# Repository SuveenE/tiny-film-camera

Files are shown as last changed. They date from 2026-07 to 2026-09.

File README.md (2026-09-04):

# Tiny Film Camera

Tiny Film Camera is an open-source digital camera built around the Raspberry Pi
Zero 2 W and Camera Module 3. It can capture photos and record short video clips
using dedicated photo and video buttons, with three selectable looks (warm, cool,
and black & white) controlled by a physical slider switch. A buzzer provides
feedback for startup and photo capture, and a local photo gallery can be accessed
directly from your phone.

Read about the design and build process in
[Building my own camera](https://suveenellawela.com/thoughts/building-my-own-camera).

<p align="center">
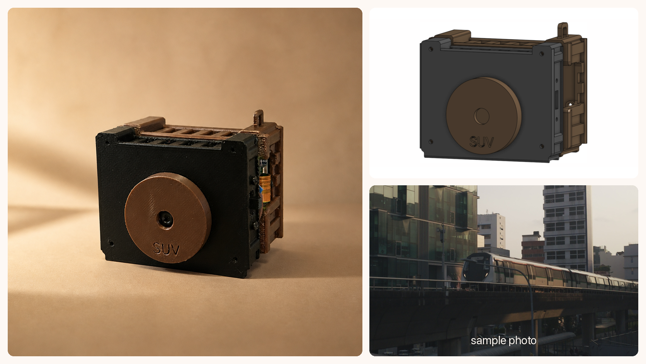
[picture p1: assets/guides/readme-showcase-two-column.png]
Tiny Film Camera assembled, the v1 CAD design, and a sample photo
  
</p>
<p align="center">
  <sub>
    <a href="assets/v1/product-images/camera-launch-warm.png">Assembled camera</a> ·
    <a href="assets/v1/v1-design.png">v1 CAD design</a> ·
    <a href="assets/photo-samples/train-sample-1935x1346.jpg">Sample photo</a> ·
    <a href="assets/photo-samples/train-original-4608x2592.jpg">Original photo (4608 × 2592)</a>
  </sub>
</p>

## What it does

- Use dedicated physical buttons for photos and short video clips.
- Choose Warm, Cool, or Black & white with a three-position hardware switch.
- Capture, browse, download, and delete photos from a phone on the same Wi-Fi.
- Monitor the Waveshare UPS battery from the web interface.
- Apply configurable exposure, white-balance, focus, rotation, and JPEG settings.
- Start the web app and hardware daemons automatically with systemd.

## Hardware

- Raspberry Pi Zero 2 W
- Raspberry Pi Camera Module 3
- Waveshare UPS HAT (C)
- Two momentary buttons (photo and video)
- Optional passive buzzer and SS23D32 three-position switch
- 3D-printed enclosure from [`assets/`](assets/README.md)

See the complete [bill of materials](docs/bom.md) and [setup guide](docs/setup.md).

### Components and wiring

<table>
  <tr>
    <td align="center" width="50%">
      <a href="assets/guides/components.png">
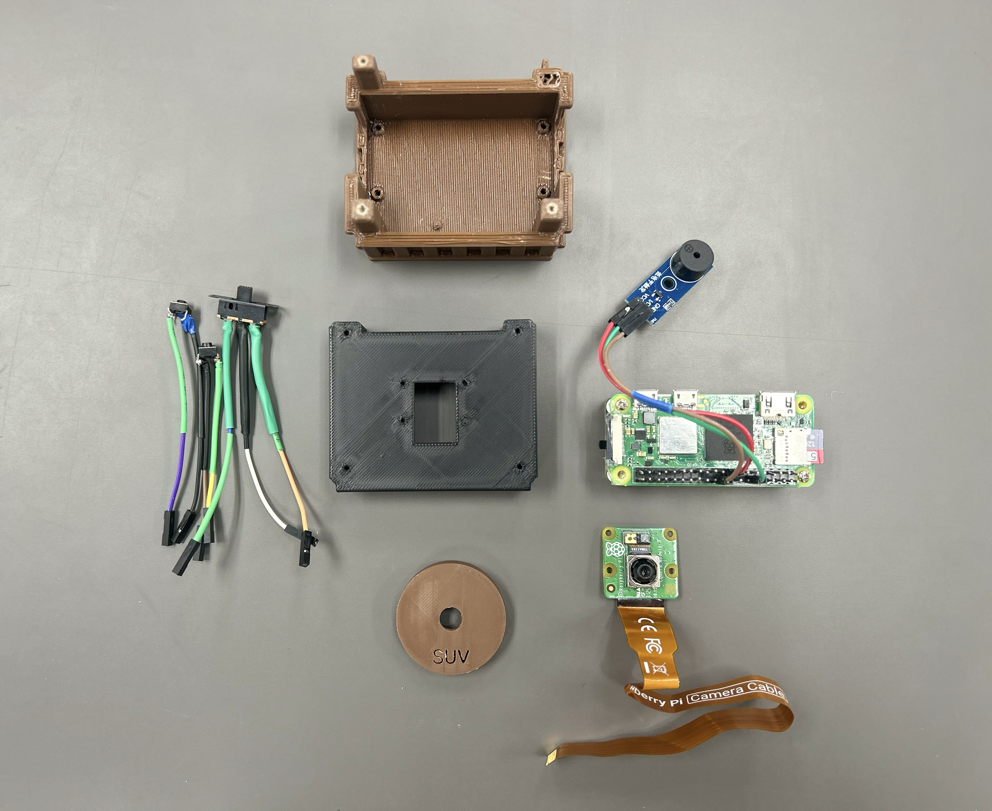
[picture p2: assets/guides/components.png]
Components used to build Tiny Film Camera
        
      </a>
      <br />
      <strong>Components</strong>
    </td>
    <td align="center" width="50%">
      <a href="assets/guides/wiring.png">
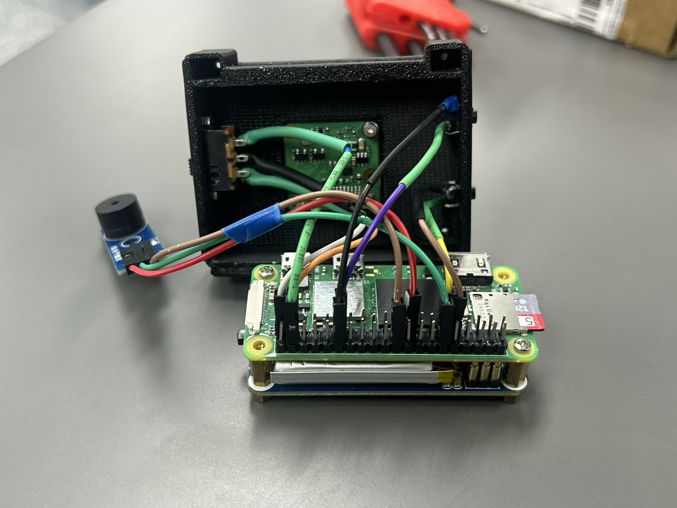
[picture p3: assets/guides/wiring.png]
Tiny Film Camera wiring guide
        
      </a>
      <br />
      <strong>Wiring</strong>
    </td>
  </tr>
</table>

## CAD designs

Browse all [Tiny Film Camera CAD components on Onshape](https://cad.onshape.com/documents?nodeId=a67770dd4e9bb35af20c342a&resourceType=folder).
Download the [printable enclosure files on Printables](https://www.printables.com/model/1827732-raspberry-pi-zero-2-w-camera-module-3-ups-hat-encl/files).

<table>
  <tr>
    <td align="center" width="50%">
      <a href="assets/v1/cad-demo-v1.mp4">
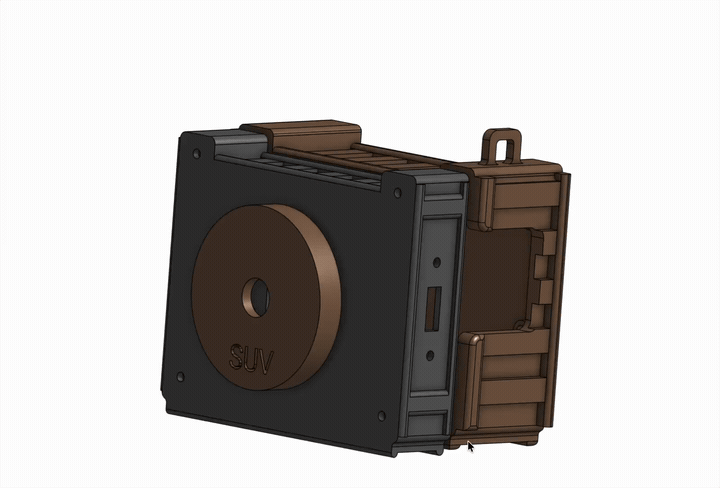
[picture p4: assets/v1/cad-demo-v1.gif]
Animated view of the assembled Tiny Film Camera v1 enclosure
        
      </a>
      <br />
      <strong>Assembled camera</strong>
    </td>
    <td align="center" width="50%">
      <a href="assets/v1/v1-cad.png">
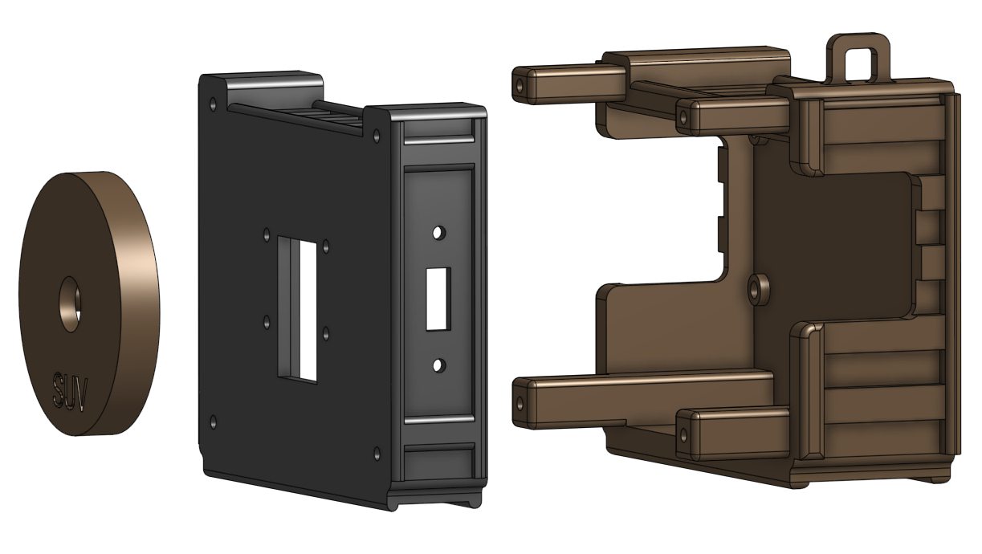
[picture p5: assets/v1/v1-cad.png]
Tiny Film Camera v1 CAD design
        
      </a>
      <br />
      <strong>v1 CAD design</strong>
    </td>
  </tr>
</table>

## Quick start

On a Raspberry Pi running Raspberry Pi OS:

```bash
git clone https://github.com/SuveenE/tiny-film-camera.git
cd tiny-film-camera

sudo apt update
sudo apt install -y \
  ffmpeg python3-picamera2 python3-av python3-pil python3-gpiozero \
  python3-smbus i2c-tools

cp .env.example .env
./scripts/install_service.sh --enable-now
```

Open `http://<pi-ip>:8000` from a phone on the same Wi-Fi network. Captures are
saved under `data/captures/`.

<p align="center">
  <a href="assets/web-app.jpg">
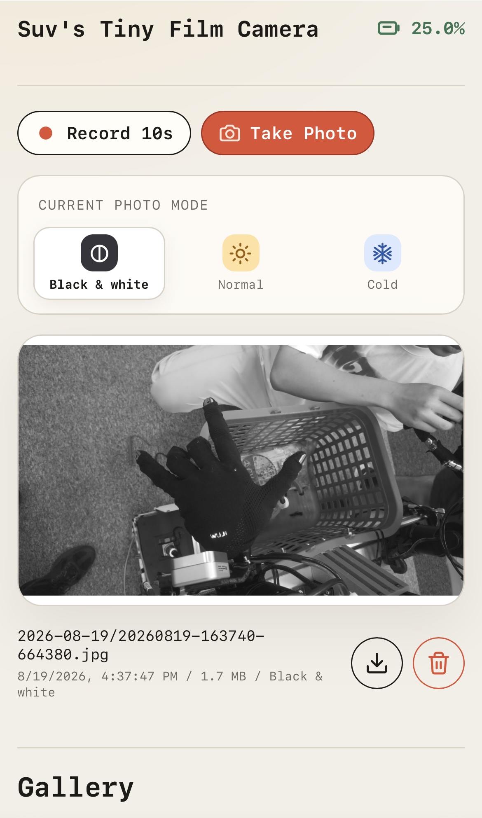
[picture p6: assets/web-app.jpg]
Tiny Film Camera web app showing capture controls, photo modes, battery level, and gallery
    
  </a>
</p>

> [!WARNING]
> The web interface has no authentication. Use it only on a trusted local
> network and do not expose port `8000` to the internet.

## Use it

Take a photo or record a ten-second video from the command line:

```bash
python3 src/tiny-film-cam/capture.py
python3 src/tiny-film-cam/record.py --duration 10
```

Customize the camera, GPIO pins, filters, battery calibration, and service
settings in [`.env.example`](.env.example), then copy the values you need into
your local `.env`.

## Build guides

- [Button, slider, and buzzer wiring](docs/wiring.md)
- [Camera and Raspberry Pi setup](docs/setup.md)
- [Physical shutter](docs/shutter-button.md)
- [Passive buzzer](docs/buzzer.md)
- [Photo-filter switch](docs/filter-switch.md)
- [Commands and service management](docs/commands.md)
- [Troubleshooting](docs/debug.md)
- [Enclosure and printable assets](assets/README.md)

## Limitations

- The Raspberry Pi takes approximately 30 seconds to 1 minute to fully start
  up, so there is a short wait before the camera is ready to use.
- Each photo takes approximately 3 to 6 seconds to process because images are
  captured at full resolution.

## License

Code and original CAD are available under the [MIT License](LICENSE).
Third-party enclosure models retain their upstream Creative Commons licenses;
see [`assets/README.md`](assets/README.md) for attribution.

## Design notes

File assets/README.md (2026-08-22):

# 3D-printable case assets

STL and OpenSCAD files for the tiny-film hardware enclosure.

Original project files under `assets/` (C-bracket spacers and generators) are
covered by the repository [MIT License](../LICENSE). Third-party Printables
models keep their upstream licenses, listed below.

## Photo samples

Full-resolution camera samples, preserved without recompression:

- `photo-samples/train-original-4608x2592.jpg` — original landscape photo,
  4608 × 2592 pixels
- `photo-samples/train-zoomed-1170x2080.jpg` — zoomed-in portrait view,
  1170 × 2080 pixels
- `photo-samples/train-sample-1935x1346.jpg` — landscape sample photo,
  1935 × 1346 pixels

## README collages

- `guides/readme-showcase-with-sample.png` — original showcase with an added
  portrait sample column
- `guides/readme-showcase-two-column.png` — assembled camera on the left, with
  the front-facing CAD card and landscape sample stacked on the right

Regenerate the collages from their checked-in source images:

```bash
python3 assets/guides/generate-readme-showcase.py
python3 assets/guides/generate-readme-showcase-two-column.py
```

## v1 assets

Current enclosure parts, reference renders, and a compressed CAD demo:

- `v1/bottom-cover-v1.stl` — bottom cover
- `v1/camera-cover-v1.stl` — camera cover
- `v1/top-cover-v1.stl` — top cover
- `v1/v1-design.png` — assembled enclosure render
- `v1/v1-cad.png` — CAD workspace render
- `v1/cad-demo-v1.mp4` — short, web-friendly CAD model demo
- `v1/product-images/camera-launch-clean.png` — clean studio product photo
- `v1/product-images/camera-launch-dark.png` — dark studio product photo
- `v1/product-images/camera-launch-warm.png` — warm studio product photo

## Third-party models

### Raspberry Pi Zero 2 Case MK3 Camera

- **Designer:** [XenoTechie](https://www.printables.com/@XenoTechie_72441)
- **Source:** https://www.printables.com/model/799255-raspberry-pi-zero-2-case-mk3-camera
- **License:** [Creative Commons Attribution 4.0 (CC BY)](https://creativecommons.org/licenses/by/4.0/)
- **Files in this repo:**
  - `v0/pi-zero-2w-camera-case-top.stl` — top cover (unmodified)
  - `v0/pi-zero-2w-camera-plate-suv-logo.stl` — camera plate
    remixed with custom “SUV” branding (derivative of the upstream camera
    plate; redistributed under the same CC BY terms with attribution)

### Raspberry Pi Zero 2 WH Waveshare UPS Case

- **Designer:** [PiotrWolinski](https://www.printables.com/@PiotrWolinski_579340)
- **Source:** https://www.printables.com/model/1546215-raspberry-pi-zero-2-wh-waveshare-ups-case
- **License:** [Creative Commons Attribution-ShareAlike 4.0 (CC BY-SA)](https://creativecommons.org/licenses/by-sa/4.0/)
- **Files in this repo:**
  - `v0/pi-zero-2w-waveshare-ups-case-base.stl` — base case (unmodified).
    ShareAlike applies to this file and any adaptations of it.

## Original project files

- `v0/c-bracket-25mm-gap-2.8mm-holes.scad` / `.stl` — 25 mm C-shaped
  spacer with 2.8 mm holes
- `v0/c-bracket-20mm-gap-2.8mm-holes.stl` — 20 mm spacer with 2.8 mm holes
- `v0/c-bracket-20mm-gap-2.1mm-2.8mm-holes.scad` / `.stl` — 20 mm spacer
  with asymmetric 2.1 mm and 2.8 mm holes
- `v0/generate-c-bracket-25mm-gap.py` and
  `v0/generate-c-bracket-20mm-gap.py` — CadQuery STL generators
- `v0/assembled-camera.jpg` — photo of an assembled build

See [`v0/README.md`](v0/README.md) for the version-specific file manifest and
regeneration commands.

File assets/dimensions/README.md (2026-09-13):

# Component dimension references

Mechanical drawings and board-layout references used when designing the
tiny-film enclosure.

- `mini-slide-switch-dimensions.png` — miniature slide-switch dimensions
- `tactile-switch-dimensions.png` — 6×6 mm 4-pin momentary tactile switch
- `pi-camera-rev1.3-dimensions.jpg` — Raspberry Pi Camera board dimensions
- `pi-zero-2w-board-layout.jpg` — Raspberry Pi Zero 2 W board layout
- `pi-zero-dimensions.png` — Raspberry Pi Zero board dimensions

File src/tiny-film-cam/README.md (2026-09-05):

# tiny-film-cam

Raspberry Pi camera application and hardware integration code for Tiny Film.

This folder contains the photo and video capture paths, phone web UI, and the
shutter, battery, buzzer, and filter-switch integrations used by the systemd
services in `deploy/`. It does not include OpenAI image generation or queues.

Run one capture from the project root on the Raspberry Pi:

```bash
python3 src/tiny-film-cam/capture.py
```

Choose one of the three JPEG looks directly with:

```bash
python3 src/tiny-film-cam/capture.py --photo-filter black_and_white
python3 src/tiny-film-cam/capture.py --photo-filter normal
python3 src/tiny-film-cam/capture.py --photo-filter cool
```

If `--output` is omitted, the script writes a timestamped JPEG into
`data/captures/YYYY-MM-DD/`.

To save to a specific filename instead, pass `--output`:

```bash
python3 src/tiny-film-cam/capture.py --output photo1.jpg
```

For a Camera Module 3 full-size still, pass an explicit size:

```bash
python3 src/tiny-film-cam/capture.py --width 4608 --height 2592
```

The default image tuning is set for a film-friendly source capture:

```text
quality=95, sharpness=0.3, contrast=0.85, saturation=0.9,
ev=-0.7, awb_mode=daylight, rotation=180
```

For a more film-friendly source capture, protect highlights and reduce digital
edge bite:

```bash
python3 src/tiny-film-cam/capture.py \
  --width 4608 \
  --height 2592 \
  --sharpness 0.3 \
  --contrast 0.85 \
  --saturation 0.9 \
  --ev -0.7 \
  --awb-mode daylight \
  --rotation 180
```

To capture multiple exposure candidates from one warmed-up camera session:

```bash
python3 src/tiny-film-cam/capture.py \
  --output photo1.jpg \
  --exposure-brackets 0,-0.7,-1.0 \
  --awb-lock
```

Bracketed filenames include the EV value, such as
`photo1_ev+0p0.jpg`, `photo1_ev-0p7.jpg`, and `photo1_ev-1p0.jpg`.

Record a short video (H.264/MP4, 10s by default) into the same
`data/captures/YYYY-MM-DD/` tree:

```bash
python3 src/tiny-film-cam/record.py --duration 10
```

Video recording requires PyAV, ffmpeg, and its `libx264` encoder on the Pi
(`sudo apt install python3-av ffmpeg`) and only supports rotation 0 or 180.
PyAV preserves camera timestamps when frames arrive late. ffmpeg then converts
the recording to constant-frame-rate H.264 that plays reliably in Safari and
places the MP4 index at the front. This final conversion takes additional time
after the requested footage has been recorded, so a 10-second clip takes longer
than 10 seconds to finish. Each new video also gets a small
`<video-name>.poster.jpg` preview for Safari; poster files stay out of the
gallery and are removed with their video.

Run the capture browser:

```bash
python3 src/tiny-film-cam/web.py
```

The web app serves captures from `data/captures/` and exposes:

- `GET /`
- `GET /gallery`
- `GET /api/images` (accepts an optional `limit` query parameter up to 50)
- `POST /api/capture`
- `POST /api/record`
- `DELETE /api/captures/<capture-path>`
- `GET /image/captures/<capture-path>`
- `GET /download/captures/<capture-path>`
- `GET /api/device-details`
- `GET /api/battery`
- `GET /api/filter`
- `GET /latest-image`

For the Wes-inspired cream/cyan filter, real-photo comparisons, and capture or
post-processing commands, see [Wes filter](../../docs/wes-anderson-filter.md).

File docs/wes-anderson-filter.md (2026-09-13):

# Wes-inspired camera filter

`wes_anderson` is a deterministic cream-and-cyan grade inspired by the warm
pastels in Asteroid City. `wes_rose` is a softer pink/blue alternative. These
are original RGB transforms, not official movie LUTs. No AI, synthesis,
random grain, blur, object replacement, or queue is involved.

The grade lifts midtones, gently compresses the tonal endpoints, moves blue
fabric toward cyan and greens toward olive, and separates cream highlights
from warm golden accents. A cached 33 × 33 × 33 Pillow LUT processes the pixels.
The source should be a correctly exposed sRGB photograph, not sensor RAW.

## Capture on the Pi

Run from `/home/suveen/tiny-film`:

```bash
python3 src/tiny-film-cam/capture.py \
  --photo-filter wes_anderson \
  --sharpness 0.3 --rotation 0 \
  --keep-original
```

This writes a timestamped JPEG and filter-version sidecar under `data/captures`.
`--keep-original` also saves the same rotated, ungraded frame as
`<name>.original.png`, with a Normal sidecar. This is lossless ISP output,
not Bayer RAW. Omit the option for faster saving and less storage use.

The command uses the sensor's full 4608 × 2592 resolution. Add
`--width 2304 --height 1296` for quicker experiments. Rotation 0 is correct for
the camera's position during this experiment; the project's normal rotation
remains 180. Exposure 0 worked for this room; it is not a universal exposure.
Start there and lower exposure if important highlights clip.

The selected filter supplies contrast, saturation, EV, and warmup from its
capture profile in `photo_filters.py`. Cool and both Wes aliases use contrast
1, saturation 1, EV 0, and a 4-second warmup. Warmup lets focus, exposure, and
auto white balance settle; white balance is then locked for that capture. This
does not lock gains across separate invocations or changing lighting. CLI
options can temporarily override a profile for a controlled experiment.

## Grade an existing photograph

Run from the project root on either the Pi or a computer with Pillow:

```bash
python3 src/tiny-film-cam/grade.py original.png wes.jpg
python3 src/tiny-film-cam/grade.py original.png softer.png --strength 0.7
python3 src/tiny-film-cam/grade.py original.png rose.jpg --photo-filter wes_rose
```

Always choose a new output filename. The tool refuses to overwrite the input,
existing output, or its metadata. It honors EXIF orientation, converts tagged
ICC inputs to sRGB, and saves a JSON sidecar with source, strength, and filter
version. JPEG quality is 95 with 4:4:4 sampling; PNG preserves exact graded
pixels. Input EXIF is not copied into the output. An untagged input is assumed
to be sRGB. Profile conversion requires Pillow's ImageCms support.

Camera capture and this tool use `apply_photo_filter` from `photo_filters.py`.
Given identical RGB inputs, filter name, and strength 1, their graded pixels
are identical. JPEG files can differ if encoder settings differ.

## Physical switch

The existing **Cool** toggle now applies the same cream-and-cyan LUT as
`wes_anderson`. Keep `TINY_FILM_FILTER_RIGHT=cool` in `.env`; the selection ID
and mode badge remain `cool`. New Cool photos record **Cool · Wes pastels**,
version 4, so their metadata distinguishes this grade from earlier Cool photos.
`--photo-filter cool` and `--photo-filter wes_anderson` produce identical pixels.

After deploying, restart the shutter and web services to load the new filter.
No switch environment changes are needed. The same LUT also works when `cool`
is selected through `TINY_FILM_CAPTURE_FILTER`. The four profile controls are
no longer read from `.env`; exposure and white balance still depend on scene
lighting.

## Experiment: 5 September 2026

Real IMX708 Camera Module 3 images are in `data/captures/wes-lab-20260905/`
on the Pi and local workspace; they are intentionally ignored by Git.

- Baseline: existing camera defaults, 2304 × 1296; upside down for this placement.
- Exposure sweep: neutral ISP settings, rotation 0, 4-second warmup, EV 0,
  +0.7, +1.0; fixed color gains and lens position across the sweep.
  EV +0.7 put about 7% of channel samples at 254 or above. EV 0 retained
  highlight detail, so the LUT supplies the brightness lift instead.
- First iteration: subtle desert and rose grades. The user chose cream/cyan,
  then correctly noted the subtle result did not look strongly Wes-inspired.
- Second iteration: stronger cream/cyan separation and midtone lift; the main
  `wes_anderson` v1 filter uses this direction.
- Full resolution: `full-wes.jpg` plus its `.original.png`; later grading and
  saving with the same JPEG settings produced a byte-identical JPEG.
- A same-room comparison after dark used identical Cool settings except for
  warmup. At 0.5 seconds, mean RGB was 171/148/108 and the image was visibly
  yellow; at 4 seconds it was 156/148/124 with cleaner cream and cyan
  separation. Cool therefore keeps the 4-second warmup in its filter profile.
- Three repeated full-resolution LUT runs produced identical pixel SHA-256
  hashes. After removing an unnecessary RGB copy, measured processing was
  6.06 seconds first run, then 2.86 and 2.45 seconds. JPEG encoding took 0.93
  seconds. Times vary with Pi load, swap, and LUT cache state; these exclude
  loading, capture warmup, and optional PNG saving.
- Full-resolution mean luma rose from 119.4 to 150.6 (0–255). The graded JPEG
  contained no pixels with any channel at 255 in this scene. This is not a
  guarantee against clipping for every input, particularly saturated colors.

One repeated capture exposed a camera shutdown stall after the files had been
saved. The capture path was changed to stop streaming immediately after the
array is captured, before PNG saving and grading. A reboot released the stuck thread. After the change, three consecutive
full-resolution captures completed: 40.63 seconds with a lossless original,
then 12.02 and 11.97 seconds for JPEG-only output, all including 4-second
warmup. This is a small repeat test, not a long-run soak test.

Useful artifacts: `final-comparison.jpg`, `iteration-two.jpg`,
`benchmark.json`, `image-metrics.json`, and exposure metadata JSON files.

## What remains to tune

This is a working color look, not a claim that an arbitrary room becomes a
Wes Anderson film still. The available scene is mostly neutral and the camera
is off-center. For a better visual test, place the camera level and directly
opposite the bed, center the headboard, remove the foreground obstruction,
and include a mustard/cream object with one cyan or red accent. Use broad,
soft light. Then compare Normal and Wes from the same frame again.

Only this indoor scene has been visually tuned. Before treating it as a
universal preset, check daylight, skin tones, foliage, saturated reds, and
low light. Evaluate white balance and exposure separately from the look;
a static LUT cannot repair mixed lighting or recover clipped sensor detail.

Reference: [Wes Anderson Color Palette Explained](https://spotlightfx.com/blog/wes-anderson-color-palette).

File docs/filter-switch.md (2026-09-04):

# Set up the photo-filter switch

The SS23D32 switch selects **Black & white**, **Normal**, or **Cool** for new
photos. Videos are unchanged.

The filter service is the only process that reads the switch GPIO pins. It
debounces the contacts and writes the current selection to
`data/filter-state.json`; web and physical-button captures read that state
immediately before taking each photo. If the state is missing, invalid, or
stale, captures fall back to **Normal** and the web badge reports the fallback.
Each saved photo also records the filter it used, so its gallery label does not
change when the switch moves later.

## 1. Identify the terminals

Power off and unplug the Pi. Choose either row of three switch terminals:

```text
outer A    common    outer B
unused     unused    unused
```

With a multimeter in continuity mode, confirm that `common` connects to one
outer terminal at each end position and neither outer terminal in the centre.

## 2. Wire one row

| Switch terminal | Raspberry Pi Zero 2 W |
| --- | --- |
| outer A | BCM GPIO 26, physical pin 37 |
| common | GND, physical pin 39 |
| outer B | BCM GPIO 20, physical pin 38 |

Leave the second row disconnected. **No resistor is required** because the code
enables the Pi's internal pull-ups. Do not connect the switch to 3.3 V or 5 V.
GPIO 26 and GPIO 20 avoid the photo button (GPIO 5), video button (GPIO 17),
buzzer (GPIO 18), and UPS I2C pins (GPIO 2 and GPIO 3).

## 3. Test the switch

Boot the Pi, open the project directory, and install `gpiozero` if needed:

```bash
sudo apt install -y python3-gpiozero
sudo systemctl stop tiny-film-filter.service 2>/dev/null || true
python3 src/tiny-film-cam/filter_switch_test.py
```

Move the switch through all three positions. The expected readings are:

| GPIO 26 | GPIO 20 | Filter |
| --- | --- | --- |
| LOW | HIGH | Black & white |
| HIGH | HIGH | Normal |
| HIGH | LOW | Cool |

Press `Ctrl+C` when finished. `LOW / LOW` indicates incorrect wiring.

If Black & white and Cool are physically reversed, add this to `.env` rather
than resoldering:

```dotenv
TINY_FILM_FILTER_LEFT=cool
TINY_FILM_FILTER_RIGHT=black_and_white
```

## 4. Install and verify the service

```bash
./scripts/install_service.sh --enable-now
sudo systemctl status tiny-film-filter.service --no-pager
curl -s http://localhost:8000/api/filter | python3 -m json.tool
```

The API should report the current `position`, `selection`, and `active_filter`.
Move the switch and rerun the `curl` command to verify each position.

## 5. Test a photo

Open `http://<pi-ip>:8000`. Confirm that the **Photo filter** badge follows the
switch, then take one photo in each position. The gallery should show the filter
used for every photo.

For service logs:

```bash
sudo journalctl -u tiny-film-filter.service -f
```

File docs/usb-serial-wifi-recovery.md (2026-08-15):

# Recover Wi-Fi over USB Serial

Use this procedure when a Raspberry Pi Zero 2 W will not join Wi-Fi and no
mini-HDMI display is available. It provides a temporary login console through
the Pi's micro-USB data port; the SD card does not need to be reflashed.

## Root cause found

The hotspot credentials stored on the boot partition were correct, the Wi-Fi
radio was enabled, and the Pi could see the 2.4 GHz hotspot. However,
`nmcli connection show` contained no saved Wi-Fi profile, so NetworkManager had
nothing to connect to automatically.

## Enable the temporary serial console

Shut down the Pi, put its SD card in another computer, and back up `config.txt`
and `cmdline.txt` from the `bootfs` partition.

Add this under `[all]` in `config.txt`:

```ini
dtoverlay=dwc2,dr_mode=peripheral
```

Add these space-separated parameters to the existing single line in
`cmdline.txt`:

```text
modules-load=dwc2,g_serial console=ttyGS0,115200 systemd.wants=serial-getty@ttyGS0.service
```

Keep all existing `cmdline.txt` content on that same line. Safely eject the SD
card and return it to the Pi.

Connect a known data-capable micro-USB cable between the computer and the Pi's
port labelled **USB**, not **PWR IN**. This cable supplies both data and power;
do not attach a second power source at the same time.

On macOS, locate and open the serial device:

```bash
ls /dev/cu.usbmodem*
screen /dev/cu.usbmodem11301 115200
```

Replace `usbmodem11301` with the name reported on the host. On Linux, the
device is usually `/dev/ttyACM0`. Press Enter if the login prompt is not
immediately visible, then log in with the Pi user account.

## Diagnose and connect

Check the radio, interface, saved profiles, and visible networks:

```bash
nmcli radio
nmcli device status
rfkill list
nmcli connection show
sudo nmcli device wifi rescan ifname wlan0
nmcli -f IN-USE,SSID,CHAN,FREQ,SIGNAL,SECURITY device wifi list ifname wlan0
```

If the hotspot is visible but has no saved profile, create one without putting
the password in shell history:

```bash
sudo nmcli --ask device wifi connect "<SSID>" ifname wlan0
```

Enter the hotspot password when prompted. Confirm the connection, IP address,
route, and automatic reconnection:

```bash
nmcli device status
ip -4 -br address show wlan0
ip route
nmcli -g connection.autoconnect connection show "<SSID>"
ping -c 3 1.1.1.1
```

## Remove the temporary console

After Wi-Fi and SSH work, remove the added `dtoverlay` line from `config.txt`
and the three added parameters from `cmdline.txt`:

```text
modules-load=dwc2,g_serial
console=ttyGS0,115200
systemd.wants=serial-getty@ttyGS0.service
```

Reboot the Pi. Removing the temporary console avoids leaving a physical USB
login interface enabled.

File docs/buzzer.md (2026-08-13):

# Feedback Buzzer

Add an optional passive buzzer so the physical shutter gives audible cues.
The shutter daemon (`src/tiny-film-cam/shutter_daemon.py`) drives these sounds:

| Sound | When |
|---|---|
| **minimal** | Startup settled and Picamera2 detected the camera (default ready cue) |
| **click** | Frame captured (default; shorter/softer tick than minimal) |
| **gentle** | Frame-captured option with a descending two-note cue |
| **shutter** | Frame-captured option with two dry mechanical-style taps |
| **sparkle** | Frame-captured option with a bright three-note arpeggio |
| **chirp** | Video recording started |
| **double** | Video saved |
| **alert** | Capture or recording failed |

By default the shutter daemon uses a **passive** buzzer on **BCM GPIO 18**.
Leave `TINY_FILM_BUZZER_PIN` blank in `.env`, or pass `--no-buzzer`, to disable.

## Hardware

This project uses a **passive** buzzer module (PWM-driven, not an active beeper
with a built-in oscillator). The BOM lists the module with pins **VCC**, **I/O**,
and **GND**.

## Wiring

Avoid BCM GPIO 5 (photo button), BCM GPIO 17 (video button), and BCM GPIO 2/3
(UPS HAT I2C). Use **BCM GPIO 18** (physical pin 12):

```
Buzzer VCC ──→ 3V3          (physical pin 1 or 17)
Buzzer GND ──→ GND          (physical pin 6 or 14)
Buzzer I/O ──→ BCM GPIO 18  (physical pin 12)
```

Power the module from **3.3V**, not 5V — the Pi GPIO is 3.3V and matches the
module's 3.3–5.5V supply range.

## Test the sounds

With the module wired, run the demo from the project root on the Pi:

```bash
python3 src/tiny-film-cam/buzzer.py
```

Or audition the four photo sounds individually:

```bash
python3 src/tiny-film-cam/buzzer.py --sound gentle --volume 1.0
python3 src/tiny-film-cam/buzzer.py --sound shutter --volume 1.0
python3 src/tiny-film-cam/buzzer.py --sound sparkle --volume 1.0
python3 src/tiny-film-cam/buzzer.py --sound minimal --volume 1.0
```

The old `--sound beep` name remains as an alias for `gentle`.

If those four still appear to have the same pitch, run the diagnostic at full
volume:

```bash
python3 src/tiny-film-cam/buzzer.py --sound pitch-test --volume 1.0
```

It plays a long 1.5 kHz tone followed by a long 2.5 kHz tone. A passive buzzer
will produce two unmistakably different pitches. If both pitches sound the
same, the connected module is an **active buzzer** with its own fixed-frequency
oscillator; software can vary only its pulse rhythm, not its pitch.

Default pin is BCM 18. Override with `--pin` if needed. Use `--active` only if
you wired a simple on/off active buzzer instead.

Passive modules with a drive transistor ignore PWM duty cycle (they stay full
loud while the pin is high). Loudness is controlled by bursting the tone
on/off — lower `--volume` means shorter bursts. Compare:

```bash
python3 src/tiny-film-cam/buzzer.py --sound gentle --volume 0.10
python3 src/tiny-film-cam/buzzer.py --sound gentle --volume 0.3
```

## Using it with the shutter

No `.env` entries are required for the default wiring (GPIO 18, passive).
With the defaults, the daemon waits for systemd to finish booting, allows five
more seconds for startup disk activity to settle, waits until Picamera2 detects
the camera, and then plays `minimal` once
at volume `0.90`. When the daemon is run outside systemd, only the five-second
settle delay applies. A softer `click` at volume `0.30` plays immediately after
the camera returns a frame, before rotation, JPEG encoding, and disk saving.
If an existing `.env` overrides older buzzer defaults, set:

```bash
TINY_FILM_BUZZER_READY_DELAY_SECONDS=5
TINY_FILM_BUZZER_PHOTO_SOUND=click
TINY_FILM_BUZZER_VOLUME=0.90
TINY_FILM_BUZZER_PHOTO_VOLUME=0.30
```

Restart the shutter service after deploying code that includes the buzzer:

```bash
sudo systemctl restart tiny-film-shutter.service
```

Or run the daemon directly:

```bash
python3 src/tiny-film-cam/shutter_daemon.py
```

To disable sound, leave the pin blank in `.env` or pass `--no-buzzer`:

```bash
TINY_FILM_BUZZER_PIN=
```

```bash
python3 src/tiny-film-cam/shutter_daemon.py --no-buzzer
```

## Configuration

| Setting | Env var | CLI flag | Default |
|---|---|---|---|
| Buzzer pin | `TINY_FILM_BUZZER_PIN` | `--buzzer-pin` / `--no-buzzer` | `18` (blank = disabled) |
| Buzzer type | `TINY_FILM_BUZZER_ACTIVE` | `--buzzer-active` / `--buzzer-passive` | passive |
| Ready settle delay | `TINY_FILM_BUZZER_READY_DELAY_SECONDS` | `--buzzer-ready-delay` | `5` seconds after boot finishes |
| Photo sound | `TINY_FILM_BUZZER_PHOTO_SOUND` | `--buzzer-photo-sound` | `click` |
| Ready/video volume | `TINY_FILM_BUZZER_VOLUME` | `--buzzer-volume` | `0.90` |
| Photo volume | `TINY_FILM_BUZZER_PHOTO_VOLUME` | `--buzzer-photo-volume` | `0.30` |

## Notes

- The buzzer is best-effort: if `gpiozero` is missing or the pin can't be
  claimed, the daemon logs a warning and keeps capturing silently.
- Only the physical shutter path beeps. Web UI captures already show on-screen
  confirmation and run in a separate process.
- Tones play on a background thread, so they never delay the next capture.
- Stay near **1.5–2.5 kHz** for this module; that is its claimed tone range.
- A passive piezo can only make simple square-wave tones, not play sampled
  camera audio. The presets use short timing and musical intervals to make the
  most of that hardware.
- Burst volume gating retains at least three complete carrier cycles per pulse
  so low-volume playback does not mask the selected pitch.
- Volume is burst density rather than electrical amplitude: `1.0` drives the
  carrier continuously, while `0.35` drives it for roughly 35% of the playback
  time. Perceived loudness is not linear and varies by buzzer module.

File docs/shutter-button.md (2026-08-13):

# Photo and Video Buttons

Wire two 4-pin momentary tactile switches to give photo and video capture their
own physical buttons. The shutter daemon (`src/tiny-film-cam/shutter_daemon.py`)
listens for both and captures using the same settings as the web UI.

Press the **photo button** for a still image. Press the **video button** to
record one video clip (10 seconds by default).

## Wiring

A 4-pin tactile switch has two pairs of internally connected legs. For each
button, use one leg from each side of the switch—not two legs from the same
connected pair. Confirm the sides with a continuity tester if the switch body
does not make them clear.

```
Photo button, one side ──→ BCM GPIO 5 (physical pin 29)
Photo button, other side ─→ GND       (physical pin 30, or any GND)

Video button, one side ──→ BCM GPIO 17 (physical pin 11)
Video button, other side ─→ GND        (physical pin 9, or any GND)
```

The two buttons can share a GND connection. On each 4-pin switch, the unused
two legs can be left unconnected; they duplicate the connected legs for
mechanical stability.

The daemon enables the Pi's internal pull-up resistor on both GPIOs by default,
so each reads HIGH at rest and goes LOW when its button is pressed. No external
resistors are required. Power the Pi off before changing the wiring, and do not
connect either button to 5 V.

## Running

```bash
python3 src/tiny-film-cam/shutter_daemon.py
```

Or enable the systemd service for auto-start on boot:

```bash
./scripts/install_service.sh --enable-now
```

The service file is at `deploy/tiny-film-shutter.service`.

## Configuration

| Setting | Env var | CLI flag | Default |
|---|---|---|---|
| Photo GPIO pin | `TINY_FILM_PHOTO_BUTTON_PIN` | `--photo-pin` | 5 |
| Video GPIO pin | `TINY_FILM_VIDEO_BUTTON_PIN` | `--video-pin` | 17 |
| Pull direction (both) | `TINY_FILM_BUTTON_PULL_UP` | `--pull-up` / `--pull-down` | pull-up |
| Debounce time | `TINY_FILM_BUTTON_BOUNCE_SECONDS` | `--bounce-time` | 0.15 s |
| Video length | — | `--video-duration` | 10 s |

`TINY_FILM_BUTTON_PIN` and `--pin` remain supported as legacy names for the
photo pin. The new photo-specific setting takes precedence.

When upgrading an existing installation that still has
`TINY_FILM_BUTTON_PIN=17`, replace it with the explicit current mapping:

```dotenv
TINY_FILM_PHOTO_BUTTON_PIN=5
TINY_FILM_VIDEO_BUTTON_PIN=17
```

All capture settings (quality, EV, rotation, AWB, etc.) are inherited from env
vars or can be passed as CLI flags — run with `--help` for the full list.

For optional audible feedback from a passive buzzer module, see
[buzzer.md](buzzer.md).

## Notes

- Button presses are queued and handled in order. A press received while a
  photo or video is in progress runs as soon as the camera is free, without
  overlapping camera access.
- Holding a button does not change its action or repeatedly trigger it: the
  photo button takes one photo and the video button records one fixed-length
  clip per press.
- Photos and videos land in the same output directory as the web UI captures, so
  they appear in the gallery immediately.
- If using pull-down wiring instead, connect the switch between GPIO and 3V3
  and pass `--pull-down`.

## Readiness and repeated-photo test

The startup ready cue now plays only after system startup has settled and
Picamera2 detects a camera. Wait for that cue before taking the first photo. The
same moment appears in the service log as `Tiny Film is ready for photos`.

First test repeated camera capture without involving the physical switch. Stop
the two camera-using services, load the deployed settings, and run five
simulated presses exactly five seconds apart:

```bash
sudo systemctl stop tiny-film-shutter.service tiny-film-web.service
set -a
source .env
set +a
python3 src/tiny-film-cam/shutter_diagnostic.py --count 5 --interval 5
sudo systemctl start tiny-film-web.service tiny-film-shutter.service
```

A successful run ends with `Diagnostic PASSED: 5/5 requests completed`. It also
prints the time from each request to its sensor frame and saved JPEG. A failed
run exits non-zero and prints the exception for the failed request.

Then test the physical button while following the service log:

```bash
sudo journalctl -u tiny-film-shutter.service -f -o cat
```

After the ready cue, press the photo button five times with at least five
seconds between presses. Each press must produce one uninterrupted sequence of
messages with the same request number:

```text
Photo request #1 queued
Photo request #1 started ... after button press
Saved 1 photo(s): ...
Photo request #1 finished in ...
```

If a press has no `queued` message, investigate the button wiring or GPIO
input. If it queues and then logs `Capture failed`, investigate the camera or
capture pipeline. A large `started ... after button press` value means an
earlier photo or video was still using the camera; the request remains queued
instead of being discarded.

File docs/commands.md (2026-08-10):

# Commands

## Take a photo
```bash
rpicam-still -o photo1.jpg --quality 95 --sharpness 0.5 --contrast 0.9 --saturation 0.9
```

## Take a film-friendlier highlight-protected photo
```bash
python3 src/tiny-film-cam/capture.py \
  --output photo1.jpg \
  --quality 95 \
  --sharpness 0.3 \
  --contrast 0.85 \
  --saturation 0.9 \
  --ev -0.7 \
  --awb-mode daylight \
  --rotation 180
```

## Take an exposure bracket
```bash
python3 src/tiny-film-cam/capture.py \
  --output photo1.jpg \
  --exposure-brackets 0,-0.7,-1.0 \
  --awb-lock
```

## Take a photo with the Python capture code
```bash
python3 src/tiny-film-cam/capture.py
```

## Take a full-size Camera Module 3 photo
```bash
python3 src/tiny-film-cam/capture.py --width 4608 --height 2592
```

## Record a short video (10s default)
```bash
python3 src/tiny-film-cam/record.py
```

## Record a custom-length video
```bash
python3 src/tiny-film-cam/record.py --duration 5 --width 1920 --height 1080 --fps 15
```

## Transfer photos to local machine
```bash
scp -r <pi-user>@<pi-ip>:/home/<pi-user>/tiny-film/data/captures .
```

Example (Pi over phone hotspot):
```bash
scp -r suveen@172.20.10.2:/home/suveen/tiny-film/data/captures .
```

## Test the feedback buzzer
```bash
python3 src/tiny-film-cam/buzzer.py
```

## Play one buzzer sound
```bash
python3 src/tiny-film-cam/buzzer.py --sound sparkle --volume 1.0
python3 src/tiny-film-cam/buzzer.py --sound minimal --volume 1.0
```

## Check whether the buzzer can change pitch
```bash
python3 src/tiny-film-cam/buzzer.py --sound pitch-test --volume 1.0
```

## Install boot services
```bash
./scripts/install_service.sh --enable-now
```

## Restart services
```bash
./scripts/restart_services.sh
```

## Service status
```bash
sudo systemctl status tiny-film-web.service tiny-film-shutter.service tiny-film-battery.service --no-pager
```

## Take a photo through the web server
```bash
curl -X POST http://localhost:8000/api/capture
```

## Record a video through the web server
```bash
curl -X POST http://localhost:8000/api/record
```

## Read battery details through the web server
```bash
curl http://localhost:8000/api/battery
```

## Follow service logs
```bash
sudo journalctl -u tiny-film-web.service -u tiny-film-shutter.service -u tiny-film-battery.service -f
```

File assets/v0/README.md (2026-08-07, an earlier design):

# Tiny Film v0 hardware files

Files use lowercase, descriptive names so printable outputs and editable sources
are easy to identify. Dimensions are in millimetres.

## Case parts

| File | Purpose |
| --- | --- |
| `pi-zero-2w-waveshare-ups-case-base.stl` | Base for the Pi Zero 2 W and Waveshare UPS HAT |
| `pi-zero-2w-camera-case-top.stl` | Camera case top cover |
| `pi-zero-2w-camera-plate-suv-logo.stl` | Camera plate remixed with the SUV logo |

These models retain their upstream Creative Commons licences and attribution;
see the parent [`assets/README.md`](../README.md).

## Additional case part

| File | Purpose |
| --- | --- |
| `pi-camera-top-cover-v0.stl` | Updated v0 Raspberry Pi camera top cover |

## C-bracket spacers

| Printable STL | Editable source | Generator |
| --- | --- | --- |
| `c-bracket-25mm-gap-2.8mm-holes.stl` | `c-bracket-25mm-gap-2.8mm-holes.scad` | `generate-c-bracket-25mm-gap.py` |
| `c-bracket-20mm-gap-2.8mm-holes.stl` | — | — |
| `c-bracket-20mm-gap-2.1mm-2.8mm-holes.stl` | `c-bracket-20mm-gap-2.1mm-2.8mm-holes.scad` | `generate-c-bracket-20mm-gap.py` |

Run the CadQuery generators from the repository root:

```bash
python3 assets/v0/generate-c-bracket-25mm-gap.py
python3 assets/v0/generate-c-bracket-20mm-gap.py
```

The generators overwrite their corresponding STL output. The bracket sources
and generators are covered by the repository MIT licence.

## Reference photo

`assembled-camera.jpg` shows the completed v0 build.

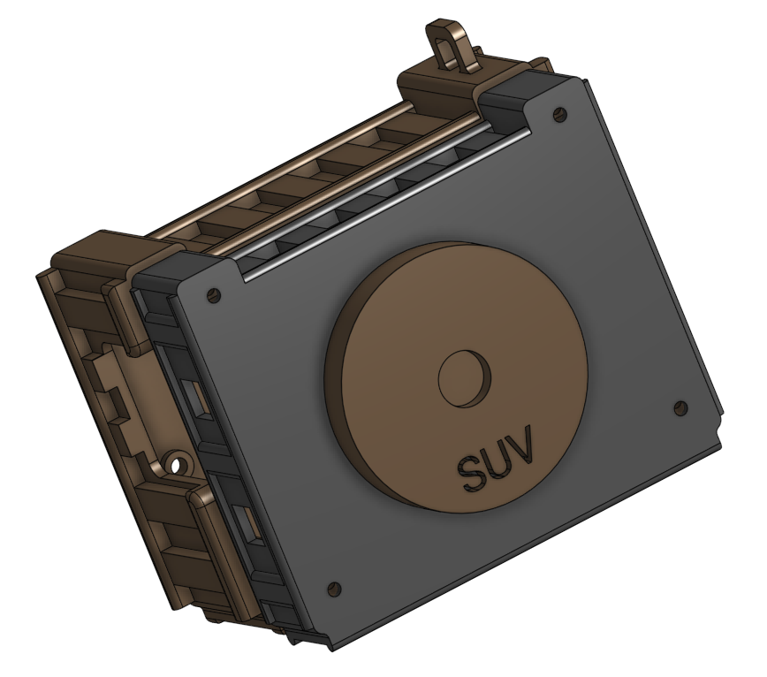
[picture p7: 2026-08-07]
assets/v1/v1-design.png

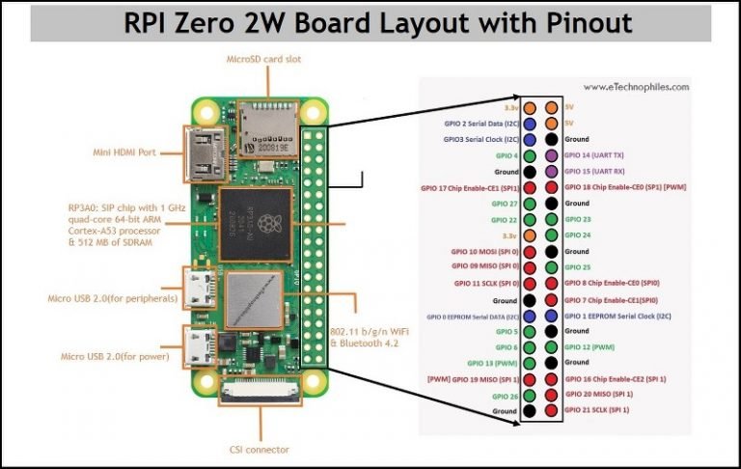
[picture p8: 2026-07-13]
assets/dimensions/pi-zero-2w-board-layout.jpg

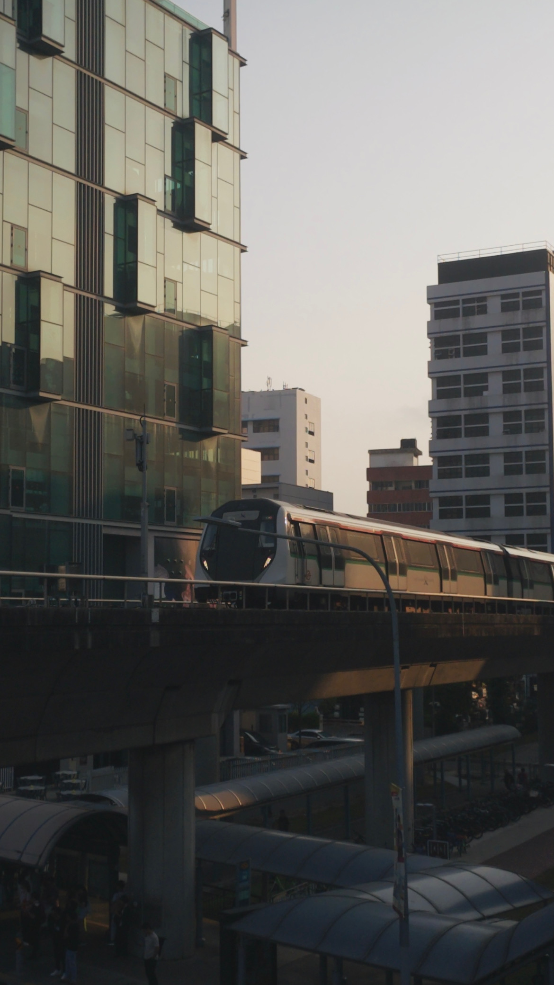
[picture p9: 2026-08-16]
assets/photo-samples/train-zoomed-1170x2080.jpg

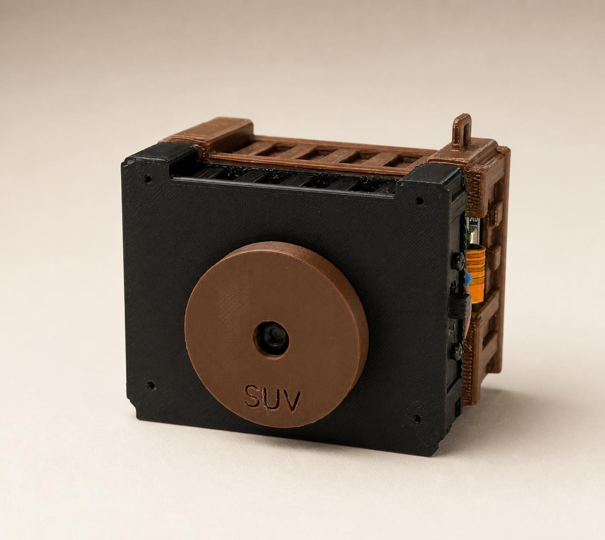
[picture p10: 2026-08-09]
assets/v1/product-images/camera-launch-clean.png

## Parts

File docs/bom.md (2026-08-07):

# Bill of Materials

- Raspberry Pi Zero 2W
- Raspberry Pi Camera Module 3
- Raspberry Pi Camera Cable (Standard to Mini, 200mm)
- MicroSD Card (A1, 32GB)
- Uninterruptible Power Supply UPS HAT For Raspberry Pi Zero, Stable 5V Power Output
- 2 × momentary tactile push buttons (one photo, one video)
- [Passive Buzzer Module (DC 3.3V/5V)](http://shopee.sg/Passive-Buzzer-Module-DC-3.3V-5V-i.199330107.27956752948)
- [3-Position 2P2T DPDT Panel Mount Slide Switch (SS23D32)](https://shopee.sg/10-x-DC-0.5A-50V-3-Position-2P2T-DPDT-Panel-Mount-Slide-Switch-SS23D32-i.1413766173.51250063839)

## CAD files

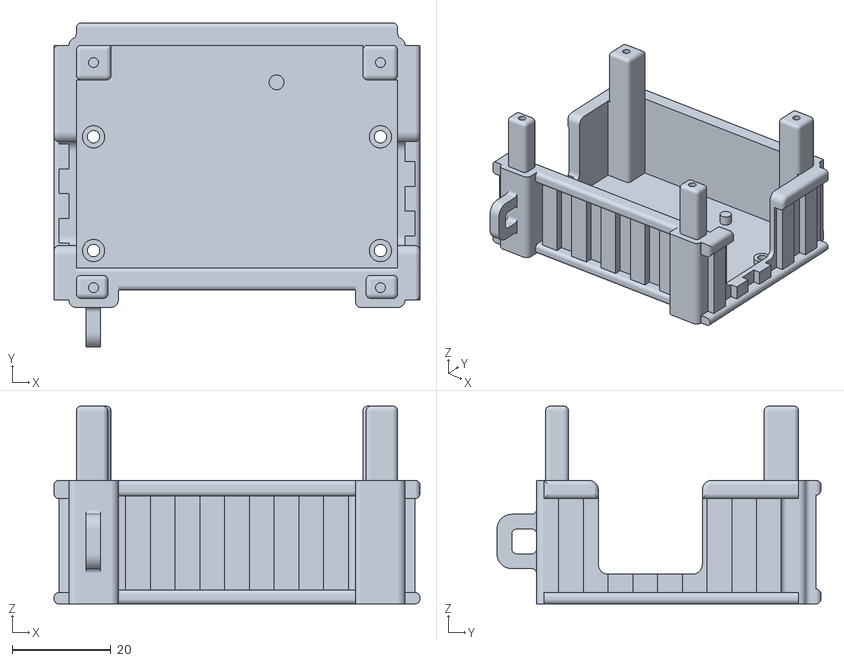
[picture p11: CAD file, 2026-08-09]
assets/v1/bottom-cover-v1.stl
74.0 x 65.5 x 40.0

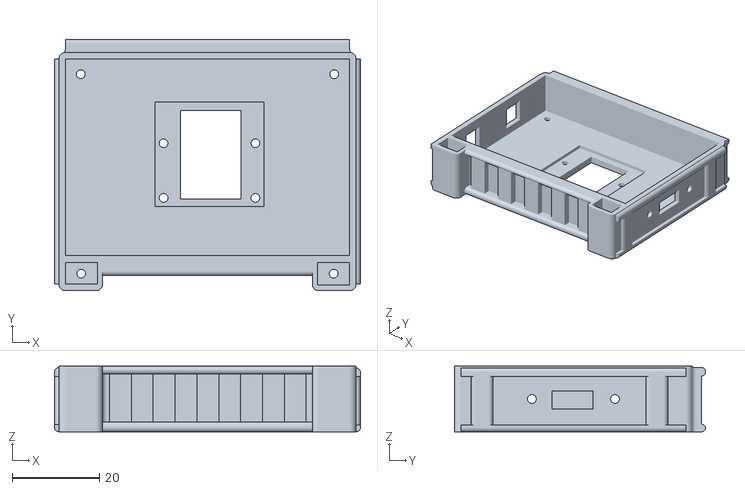
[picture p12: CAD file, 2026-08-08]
assets/v1/top-cover-v1.stl
70.0 x 57.5 x 15.0

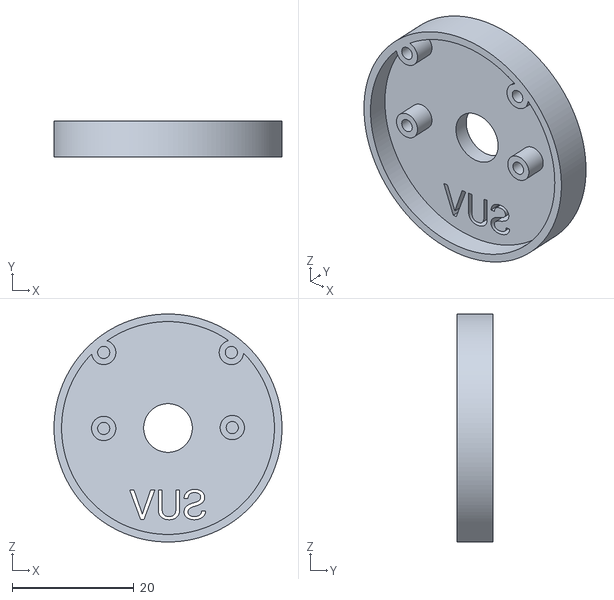
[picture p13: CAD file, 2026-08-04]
assets/v1/camera-cover-v1.stl
37.5 x 6.00 x 37.5

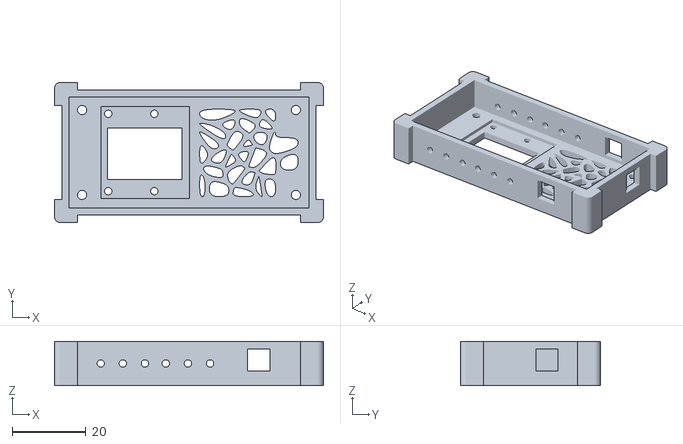
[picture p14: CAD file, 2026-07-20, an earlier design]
assets/v0/pi-camera-top-cover-v0.stl
73.0 x 38.0 x 12.0

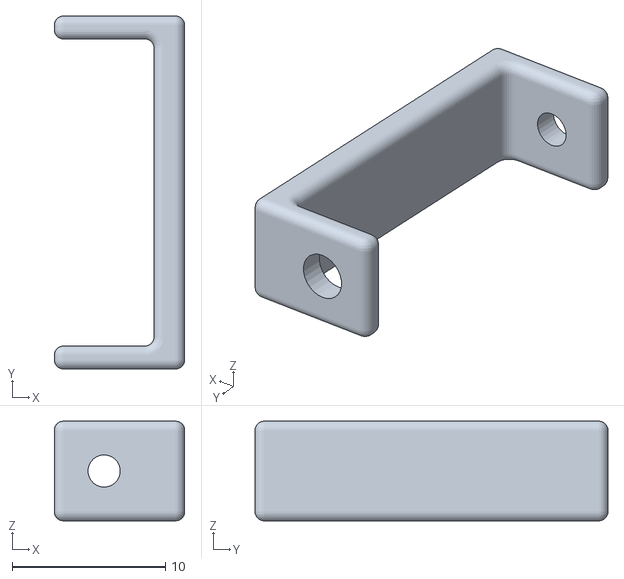
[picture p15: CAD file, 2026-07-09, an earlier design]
assets/v0/c-bracket-20mm-gap-2.1mm-2.8mm-holes.stl
8.50 x 23.0 x 6.50

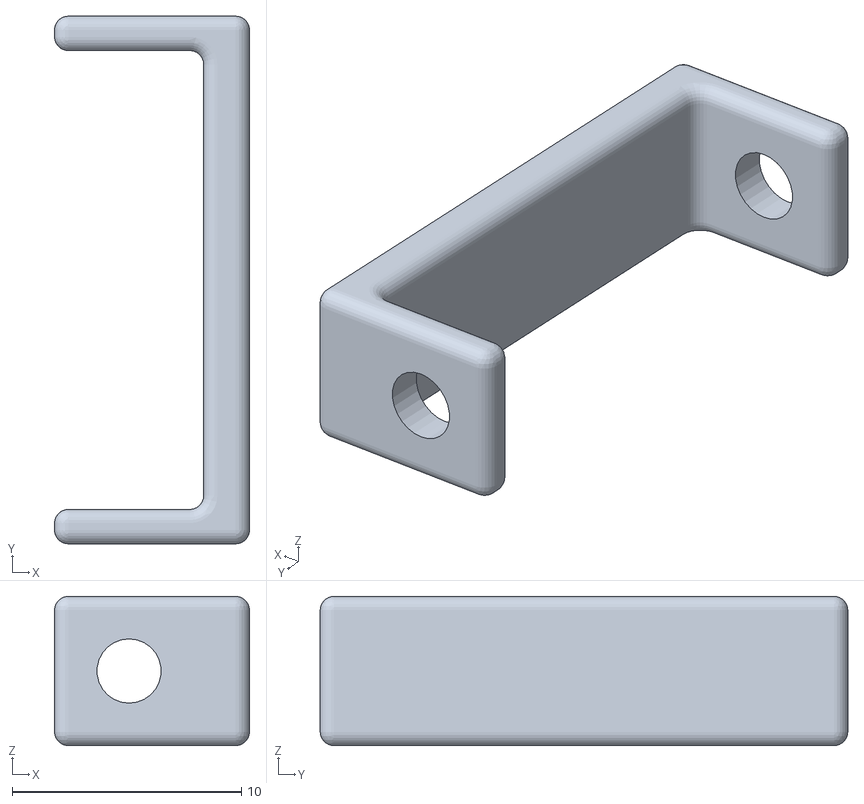
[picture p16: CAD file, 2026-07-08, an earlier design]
assets/v0/c-bracket-20mm-gap-2.8mm-holes.stl
8.50 x 23.0 x 6.50

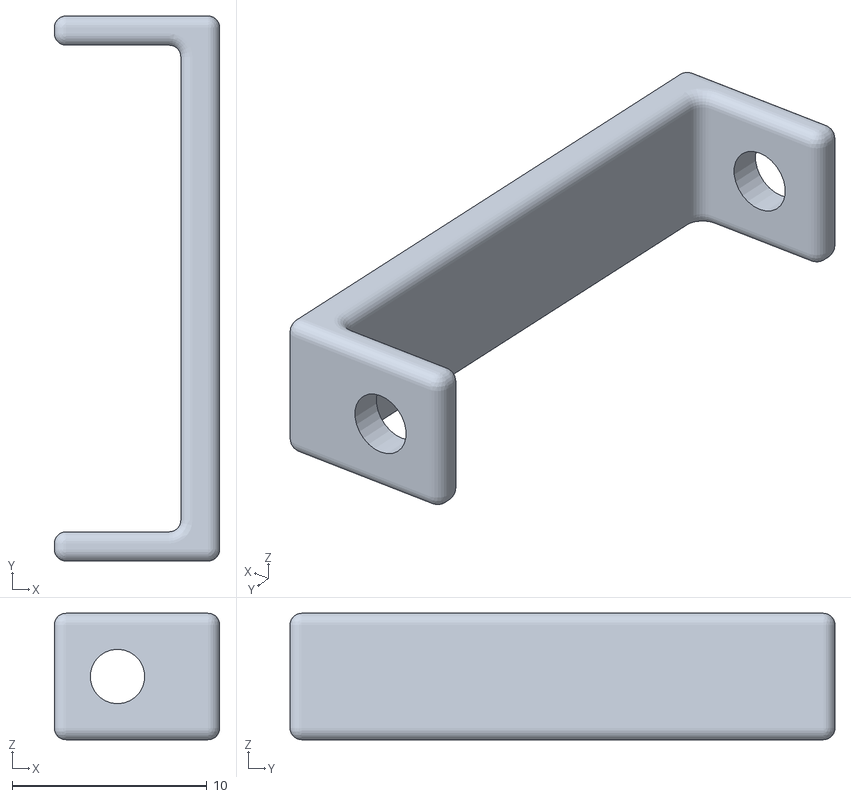
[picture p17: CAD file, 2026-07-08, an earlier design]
assets/v0/c-bracket-25mm-gap-2.8mm-holes.stl
8.50 x 28.0 x 6.50

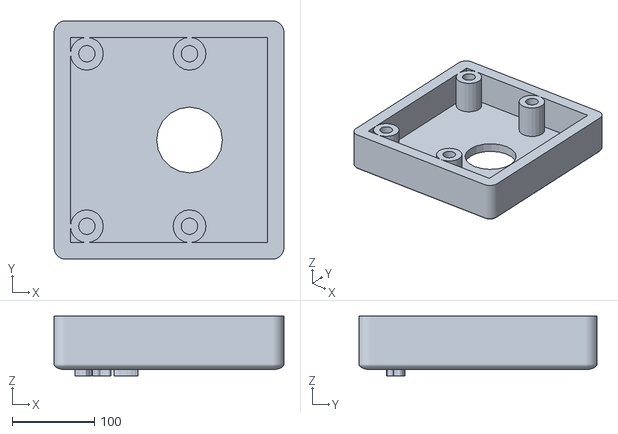
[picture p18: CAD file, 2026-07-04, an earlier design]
assets/v0/pi-zero-2w-camera-plate-suv-logo.stl
280.0 x 290.0 x 72.5

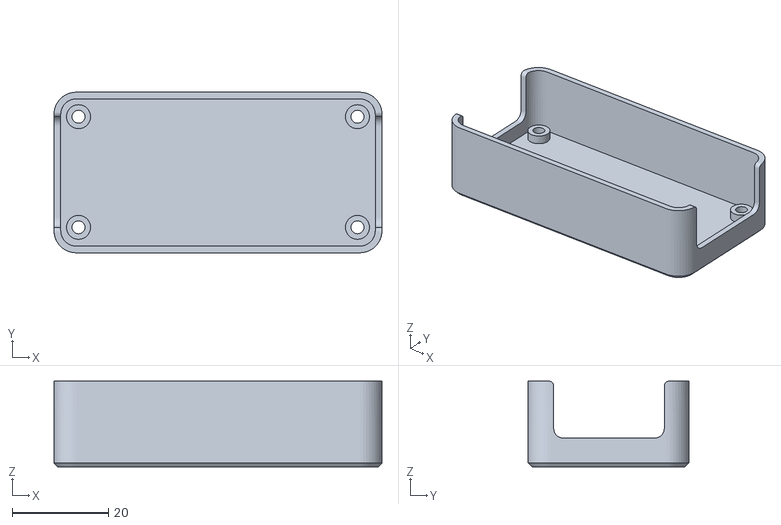
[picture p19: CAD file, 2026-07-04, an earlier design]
assets/v0/pi-zero-2w-waveshare-ups-case-base.stl
68.2 x 33.4 x 17.9

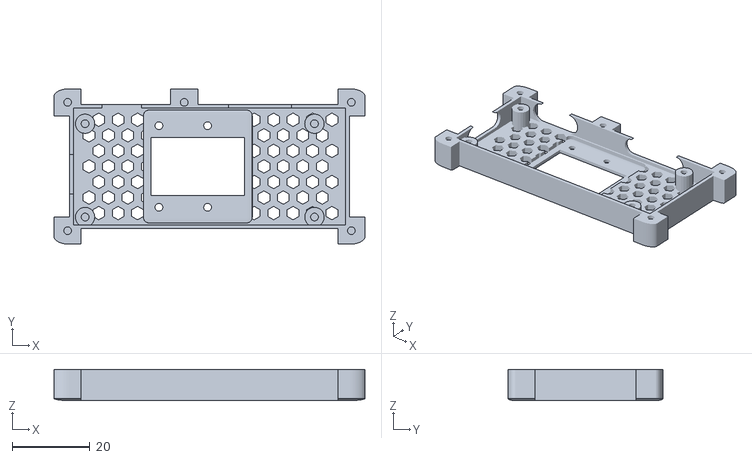
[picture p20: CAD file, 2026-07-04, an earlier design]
assets/v0/pi-zero-2w-camera-case-top.stl
80.0 x 40.0 x 8.00

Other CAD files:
assets/v0/c-bracket-20mm-gap-2.1mm-2.8mm-holes.scad
assets/v0/c-bracket-25mm-gap-2.8mm-holes.scad

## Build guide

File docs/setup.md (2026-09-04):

# Setup

1. Flash Raspberry Pi OS onto SD card with Raspberry Pi Imager
2. Insert SD card and boot — wait until you can SSH in
3. Update packages:
   ```bash
   sudo apt update && sudo apt full-upgrade -y
   ```
4. Reboot:
   ```bash
   sudo reboot
   ```
5. Test the camera:
   ```bash
   rpicam-hello -t 5000
   ```
6. Take a picture:
   ```bash
   rpicam-still -o test.jpg
   ```
   Or record a short test clip:
   ```bash
   rpicam-vid -t 5000 -o test.mp4
   ```
7. Install the camera helpers (`python3-av` preserves camera timestamps and
   `ffmpeg` finalizes browser-friendly MP4 recordings):
   ```bash
   sudo apt install -y ffmpeg python3-picamera2 python3-av python3-pil python3-gpiozero python3-smbus i2c-tools
   ```
8. Enable I2C for the Waveshare UPS HAT (C):
   ```bash
   sudo raspi-config
   ```
   Choose `Interface Options` -> `I2C` -> `Yes`, then reboot.
9. Confirm the UPS HAT is visible at address `0x43`:
   ```bash
   i2cdetect -y 1
   ```
10. Wire the photo button between BCM GPIO 5 (physical pin 29) and the adjacent
    GND (physical pin 30). Wire a separate video button between BCM GPIO 17
    (physical pin 11) and any GND pin. With the default `.env.example`
    settings, both use the Pi's internal pull-up resistors; no external
    resistors are required. See
    [shutter-button.md](shutter-button.md).
11. Optionally wire the passive buzzer: VCC to 3V3, GND to GND, and I/O to
    BCM GPIO 18 (physical pin 12). The shutter daemon enables that pin by
    default — test with `python3 src/tiny-film-cam/buzzer.py`. See
    [buzzer.md](buzzer.md).
12. Optionally wire and test the SS23D32 photo-filter switch on BCM GPIO 26 and
    20. See [filter-switch.md](filter-switch.md); no external resistors are
    required.
13. Install the Tiny Film boot services:
   ```bash
   ./scripts/install_service.sh --enable-now
   ```

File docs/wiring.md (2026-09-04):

# Wiring

Power off and unplug the Raspberry Pi before changing any wiring.

## Two buttons

| Control | First side | Other side |
| --- | --- | --- |
| Photo button | BCM GPIO 5 (physical pin 29) | GND (physical pin 30) |
| Video button | BCM GPIO 17 (physical pin 11) | GND (physical pin 9) |

The buttons can share any GND pin. For a 4-pin tactile button, connect one leg
from each side of the button; the two legs on each side are already connected
internally.

## Three-position slider

Use one row of three terminals on the SS23D32 slider and leave the other row
unconnected.

| Slider terminal | Raspberry Pi |
| --- | --- |
| Outer A | BCM GPIO 26 (physical pin 37) |
| Centre/common | GND (physical pin 39) |
| Outer B | BCM GPIO 20 (physical pin 38) |

The slider positions select:

| Slider connection | Photo filter |
| --- | --- |
| GPIO 26 connected to GND | Black & white |
| Neither outer terminal connected to GND | Normal |
| GPIO 20 connected to GND | Cool |

## Passive buzzer

| Buzzer terminal | Raspberry Pi |
| --- | --- |
| VCC | 3.3 V (physical pin 1 or 17) |
| GND | GND (physical pin 6 or 14) |
| I/O | BCM GPIO 18 (physical pin 12) |

Use a passive three-pin buzzer module with terminals labelled VCC, GND, and I/O.
Power it from 3.3 V, not 5 V.

The Pi's internal pull-up resistors are enabled for all four button and slider
GPIO inputs, so no external resistors are needed. Do not connect the buttons or
slider to 3.3 V or 5 V.

For testing and configuration details, see
[Photo and Video Buttons](shutter-button.md) and
[Photo-filter switch](filter-switch.md), and [Passive buzzer](buzzer.md).

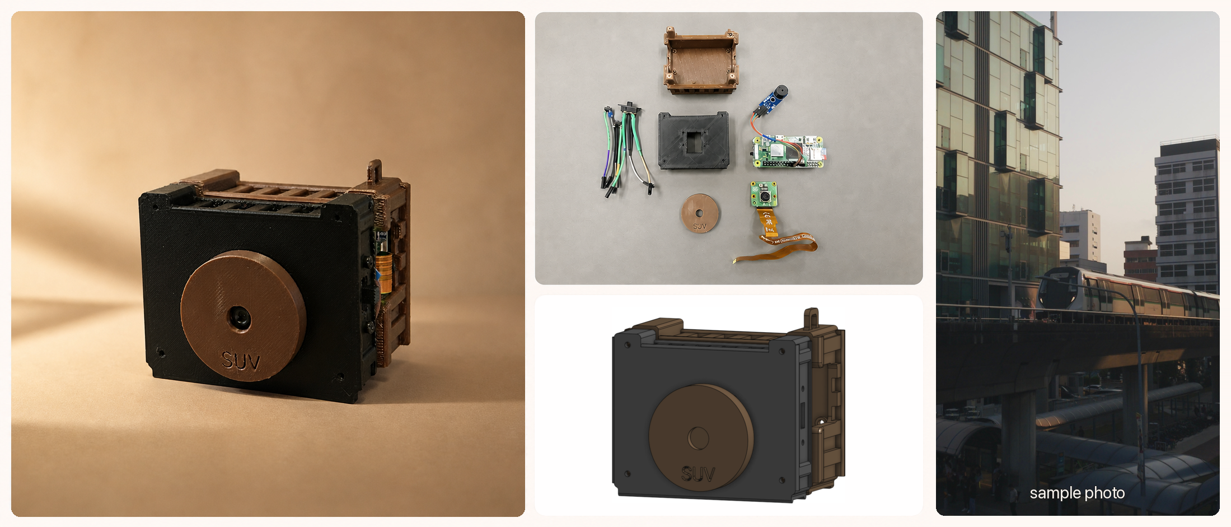
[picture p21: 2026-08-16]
assets/guides/readme-showcase-with-sample.png

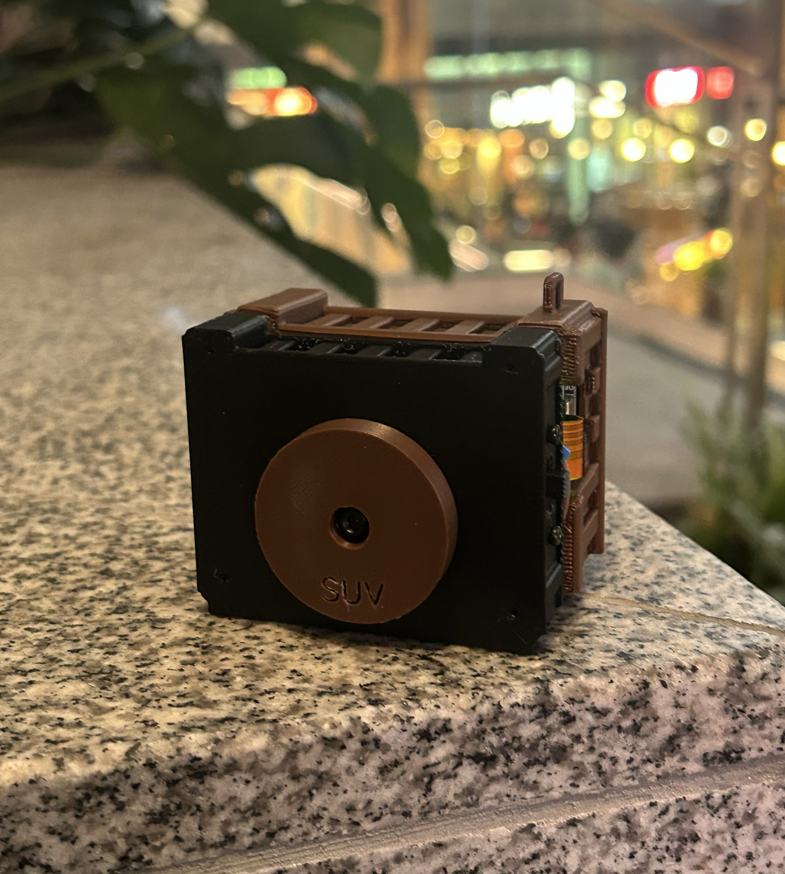
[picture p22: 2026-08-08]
assets/guides/assembled-camera.png

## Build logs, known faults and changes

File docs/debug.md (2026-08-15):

# Debug

## LED Behavior

- **Solid green** — powered and idle
- **Blinking/flickering** — reading/writing to SD card (common during boot)
- **Off** — no power, or issue with SD card/power supply

## Capture Failed: No Camera

If the phone app says `Capture failed` and mentions no Raspberry Pi camera, run:

```bash
rpicam-hello --list-cameras
```

Expected: at least one camera is listed.

If no camera appears, power down safely, reseat the camera ribbon, check the
ribbon orientation, boot again, and rerun the check before testing the web app.

## Pi Not Reachable Over the Network

If a remote tool or SSH client stops finding the Pi, check connectivity
directly:

```bash
ping <pi-ip>
ssh <pi-user>@<pi-ip>
```

Example (Pi over phone hotspot):
```bash
ping 172.20.10.2
ssh suveen@172.20.10.2
```

The `172.20.10.x` range is what a phone hotspot typically hands out, so this
address can change between hotspot sessions.

If SSH is refused, make sure the SSH service is enabled and running on the Pi
(one-time setup; needs a keyboard/monitor or another way in):

```bash
sudo systemctl enable --now ssh
```

If the Pi has no network connection and no mini-HDMI display is available, use
the [USB serial Wi-Fi recovery guide](usb-serial-wifi-recovery.md) to log in and
repair its NetworkManager profile without reflashing the SD card.

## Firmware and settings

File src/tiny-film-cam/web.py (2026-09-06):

from __future__ import annotations

import argparse
import json
import mimetypes
import shutil
import socket
from dataclasses import replace
from email.utils import formatdate
from http import HTTPStatus
from http.server import BaseHTTPRequestHandler, ThreadingHTTPServer
from pathlib import Path
from urllib.parse import parse_qs, quote, unquote, urlsplit

from battery import battery_status_from_cache
from capture_metadata import delete_capture_metadata, read_capture_metadata
from camera import (
    CameraCaptureError,
    CameraUnavailableError,
    capture_output_dir_from_env,
    capture_photo,
    capture_settings_from_env,
    record_video,
    video_poster_path,
    video_settings_from_env,
)
from photo_filters import (
    photo_filter_status_from_cache,
    selected_photo_filter_from_cache,
)


IMAGE_SUFFIXES = {".jpg", ".jpeg", ".png", ".webp"}
VIDEO_SUFFIXES = {".mp4"}
CAPTURE_SUFFIXES = IMAGE_SUFFIXES | VIDEO_SUFFIXES
HOME_GALLERY_LIMIT = 50


def media_type_for(path: Path) -> str:
    return "video" if path.suffix.lower() in VIDEO_SUFFIXES else "image"


def default_project_root() -> Path:
    return Path(__file__).resolve().parents[2]


def captures_root(project_root: Path) -> Path:
    return capture_output_dir_from_env(project_root)


def is_capture_image_file(path: Path) -> bool:
    return (
        path.is_file()
        and not path.name.startswith(".")
        and not path.name.lower().endswith(".mp4.poster.jpg")
        and path.suffix.lower() in CAPTURE_SUFFIXES
    )


def is_video_poster_file(path: Path) -> bool:
    return (
        path.is_file()
        and not path.name.startswith(".")
        and path.name.lower().endswith(".mp4.poster.jpg")
    )


def iter_capture_images(project_root: Path) -> list[Path]:
    root = captures_root(project_root)
    if not root.exists():
        return []
    return sorted(
        (path for path in root.rglob("*") if is_capture_image_file(path)),
        key=lambda path: path.stat().st_mtime_ns,
        reverse=True,
    )


def get_capture_image_by_relative_path(
    project_root: Path, relative_path: str
) -> Path | None:
    root = captures_root(project_root)
    decoded_relative = unquote(relative_path).lstrip("/")
    candidate = (root / decoded_relative).resolve()
    try:
        candidate.relative_to(root.resolve())
    except ValueError:
        return None
    if is_capture_image_file(candidate):
        return candidate
    return None


def get_capture_media_by_relative_path(
    project_root: Path, relative_path: str
) -> Path | None:
    root = captures_root(project_root)
    decoded_relative = unquote(relative_path).lstrip("/")
    candidate = (root / decoded_relative).resolve()
    try:
        candidate.relative_to(root.resolve())
    except ValueError:
        return None
    if is_capture_image_file(candidate) or is_video_poster_file(candidate):
        return candidate
    return None


def get_latest_capture_path(project_root: Path) -> Path | None:
    images = iter_capture_images(project_root)
    if not images:
        return None
    return images[0]


def build_capture_image_list(
    project_root: Path, limit: int | None = None
) -> list[dict[str, object]]:
    image_paths = iter_capture_images(project_root)
    if limit is not None:
        image_paths = image_paths[: max(0, limit)]
    return [
        build_capture_image(project_root, image_path)
        for image_path in image_paths
    ]


def parse_capture_list_limit(query: str) -> int | None:
    raw_limit = parse_qs(query).get("limit", [None])[0]
    if raw_limit is None:
        return None
    try:
        limit = int(raw_limit)
    except (TypeError, ValueError):
        return None
    if limit <= 0:
        return None
    return min(limit, HOME_GALLERY_LIMIT)


def build_capture_image(project_root: Path, image_path: Path) -> dict[str, object]:
    root = captures_root(project_root).resolve()
    relative_path = image_path.resolve().relative_to(root).as_posix()
    stat = image_path.stat()
    metadata = read_capture_metadata(image_path)
    photo_filter = metadata.get("photo_filter")
    poster_path = video_poster_path(image_path)
    poster_url = None
    if media_type_for(image_path) == "video" and poster_path.is_file():
        poster_relative_path = poster_path.resolve().relative_to(root).as_posix()
        poster_url = f"/image/captures/{quote(poster_relative_path)}"
    return {
        "filename": image_path.name,
        "relative_path": relative_path,
        "media_type": media_type_for(image_path),
        "view_url": f"/image/captures/{quote(relative_path)}",
        "download_url": f"/download/captures/{quote(relative_path)}",
        "delete_url": f"/api/captures/{quote(relative_path)}",
        "modified_unix": stat.st_mtime,
        "size_bytes": stat.st_size,
        "poster_url": poster_url,
        "photo_filter": photo_filter if isinstance(photo_filter, dict) else None,
    }


def capture_from_web(project_root: Path) -> dict[str, object]:
    settings = replace(
        capture_settings_from_env(project_root),
        photo_filter=selected_photo_filter_from_cache(project_root),
    )
    output_path = capture_photo(settings)
    try:
        output_path.relative_to(captures_root(project_root))
    except ValueError as exc:
        raise RuntimeError(
            "Capture was saved outside the configured captures directory"
        ) from exc
    return build_capture_image(project_root, output_path)


def record_from_web(project_root: Path) -> dict[str, object]:
    output_path = record_video(video_settings_from_env(project_root))
    try:
        output_path.relative_to(captures_root(project_root))
    except ValueError as exc:
        raise RuntimeError(
            "Recording was saved outside the configured captures directory"
        ) from exc
    return build_capture_image(project_root, output_path)


def remove_empty_capture_dirs(project_root: Path, start: Path) -> None:
    root = captures_root(project_root).resolve()
    current = start.resolve()
    while current != root:
        try:
            current.relative_to(root)
        except ValueError:
            return
        try:
            current.rmdir()
        except OSError:
            return
        current = current.parent


def delete_capture_image(
    project_root: Path, relative_path: str
) -> dict[str, object] | None:
    image_path = get_capture_image_by_relative_path(project_root, relative_path)
    if image_path is None:
        return None
    root = captures_root(project_root).resolve()
    deleted_path = image_path.relative_to(root).as_posix()
    deleted_name = image_path.name
    image_path.unlink()
    if media_type_for(image_path) == "video":
        video_poster_path(image_path).unlink(missing_ok=True)
    delete_capture_metadata(image_path)
    remove_empty_capture_dirs(project_root, image_path.parent)
    return {
        "ok": True,
        "filename": deleted_name,
        "relative_path": deleted_path,
    }


def format_bytes(value: int) -> str:
    amount = float(value)
    for unit in ("B", "KB", "MB", "GB"):
        if amount < 1024 or unit == "GB":
            return f"{amount:.1f} {unit}" if unit != "B" else f"{int(amount)} B"
        amount /= 1024
    return f"{amount:.1f} GB"


def local_ip_address() -> str:
    try:
        with socket.socket(socket.AF_INET, socket.SOCK_DGRAM) as sock:
            sock.settimeout(0.2)
            sock.connect(("8.8.8.8", 80))
            return str(sock.getsockname()[0])
    except OSError:
        try:
            return socket.gethostbyname(socket.gethostname())
        except OSError:
            return "127.0.0.1"


def build_device_details(project_root: Path, port: int) -> dict[str, object]:
    disk = shutil.disk_usage(project_root)
    hostname = socket.gethostname().strip() or "tiny-film"
    ip_address = local_ip_address()
    port_suffix = "" if port == 80 else f":{port}"
    images = iter_capture_images(project_root)
    latest = (
        images[0].relative_to(captures_root(project_root)).as_posix()
        if images
        else None
    )
    return {
        "hostname": hostname,
        "ip_address": ip_address,
        "app_url": f"http://{ip_address}{port_suffix}",
        "capture_count": len(images),
        "latest_capture": latest,
        "storage_status": f"{format_bytes(disk.free)} free of {format_bytes(disk.total)}",
        "storage_free_bytes": disk.free,
        "storage_total_bytes": disk.total,
    }


def render_page(page_name: str = "home") -> bytes:
    page = """
    <!doctype html>
    <html lang="en">
      <head>
        <meta charset="utf-8">
        <meta name="viewport" content="width=device-width, initial-scale=1">
        <meta name="theme-color" content="#f7f7f4">
        <title>Suv's Tiny Film Camera</title>
        <style>
          :root {
            color-scheme: light;
            --bg: #f3efe7;
            --surface: #fffdf8;
            --surface-strong: #fff;
            --fg: #1d1b17;
            --muted: #706c63;
            --line: #d9d2c5;
            --accent: #e34f32;
            --accent-dark: #a82f1e;
            --gold: #f3b83f;
            --blue: #4b78c2;
            --shadow: 0 18px 45px rgba(58, 44, 27, 0.09);
          }
          * { box-sizing: border-box; }
          body {
            margin: 0;
            background:
              radial-gradient(circle at 8% -8%, rgba(243, 184, 63, 0.2), transparent 27rem),
              var(--bg);
            color: var(--fg);
            font-family: ui-monospace, "SFMono-Regular", "SF Mono", Consolas, "Liberation Mono", Menlo, monospace;
          }
          main {
            width: min(1080px, 100%);
            margin: 0 auto;
            padding: 20px;
          }
          header {
            display: flex;
            align-items: center;
            justify-content: space-between;
            gap: 18px;
            padding: 9px 0 42px;
          }
          body[data-page="home"] .gallery-only { display: none; }
          body[data-page="gallery"] .home-only { display: none; }
          body[data-page="gallery"] .gallery-only { display: inline-flex; }
          body[data-page="gallery"] header { padding-bottom: 20px; }
          body[data-page="gallery"] .gallery-section {
            border-top: 0;
            padding-top: 6px;
          }
          h1, h2, p { margin: 0; }
          h1 {
            font-size: 20px;
            font-weight: 650;
            letter-spacing: 0;
          }
          h2 { font-size: 22px; line-height: 1.1; font-weight: 650; letter-spacing: 0; }
          section {
            border-top: 1px solid var(--line);
            padding: 20px 0 38px;
          }
          .status {
            color: var(--muted);
            font-size: 14px;
          }
          .visually-hidden {
            border: 0;
            clip: rect(0 0 0 0);
            clip-path: inset(50%);
            height: 1px;
            margin: -1px;
            overflow: hidden;
            padding: 0;
            position: absolute;
            white-space: nowrap;
            width: 1px;
          }
          .latest {
            display: grid;
            gap: 16px;
          }
          .latest-frame {
            min-height: 340px;
            border: 1px solid var(--line);
            border-radius: 20px;
            background: var(--surface-strong);
            display: grid;
            place-items: center;
            overflow: hidden;
            position: relative;
            box-shadow: var(--shadow);
          }
          .latest-frame img,
          .latest-frame video {
            display: block;
            width: 100%;
            max-height: 68vh;
            object-fit: contain;
          }
          .empty {
            color: var(--muted);
            padding: 42px 16px;
            text-align: center;
          }
          .media-error {
            color: var(--muted);
            display: grid;
            gap: 12px;
            justify-items: center;
            max-width: 380px;
            padding: 44px 24px;
            text-align: center;
          }
          .name {
            overflow-wrap: anywhere;
            font-size: 15px;
          }
          .meta {
            color: var(--muted);
            display: block;
            font-size: 13px;
            margin-top: 4px;
          }
          a.button,
          button.button {
            appearance: none;
            align-items: center;
            background: var(--surface);
            border: 1px solid var(--fg);
            border-radius: 999px;
            color: var(--fg);
            display: inline-flex;
            font-size: 14px;
            font-weight: 600;
            gap: 8px;
            padding: 8px 13px;
            text-decoration: none;
            white-space: nowrap;
          }
          button.button {
            cursor: pointer;
            font-family: inherit;
          }
          a.button.primary,
          button.button.primary {
            background: var(--accent);
            border-color: var(--accent-dark);
            color: #fff;
          }
          .button svg {
            display: block;
            fill: none;
            height: 18px;
            stroke: currentColor;
            stroke-linecap: round;
            stroke-linejoin: round;
            stroke-width: 2;
            width: 18px;
          }
          .button.record svg {
            color: var(--accent);
            fill: currentColor;
            stroke: none;
          }
          .button.primary svg {
            color: #ffe7d8;
          }
          button.button:disabled {
            cursor: wait;
            opacity: 0.55;
          }
          .actions {
            align-items: center;
            display: flex;
            gap: 8px;
            flex-wrap: wrap;
            justify-content: flex-end;
          }
          .filter-summary {
            align-items: center;
            background: rgba(255, 253, 248, 0.82);
            border: 1px solid var(--line);
            border-radius: 18px;
            display: grid;
            gap: 16px;
            grid-template-columns: minmax(145px, 0.72fr) minmax(0, 2fr);
            padding: 14px;
          }
          .filter-summary.warning {
            border-color: rgba(227, 79, 50, 0.55);
          }
          .mode-copy {
            display: grid;
            gap: 3px;
            padding: 0 4px;
          }
          .eyebrow {
            color: var(--muted);
            font-size: 11px;
            letter-spacing: 0.08em;
            text-transform: uppercase;
          }
          .mode-options {
            display: grid;
            gap: 8px;
            grid-template-columns: repeat(3, minmax(0, 1fr));
          }
          .mode-option {
            align-items: center;
            border: 1px solid transparent;
            border-radius: 13px;
            color: var(--muted);
            display: flex;
            gap: 8px;
            min-width: 0;
            padding: 8px;
          }
          .mode-option.active {
            background: var(--surface-strong);
            border-color: var(--line);
            box-shadow: 0 5px 14px rgba(58, 44, 27, 0.08);
            color: var(--fg);
            font-weight: 650;
          }
          .mode-icon {
            align-items: center;
            border-radius: 10px;
            display: inline-flex;
            flex: 0 0 auto;
            height: 34px;
            justify-content: center;
            width: 34px;
          }
          .mode-icon svg {
            display: block;
            fill: none;
            height: 19px;
            stroke: currentColor;
            stroke-linecap: round;
            stroke-linejoin: round;
            stroke-width: 1.9;
            width: 19px;
          }
          [data-filter="black_and_white"] .mode-icon {
            background: #34343a;
            color: #fff;
          }
          [data-filter="normal"] .mode-icon {
            background: #ffe1a0;
            color: #9a5d00;
          }
          [data-filter="cool"] .mode-icon {
            background: #dce9ff;
            color: #285ba9;
          }
          .battery-summary {
            align-items: center;
            color: #367552;
            display: inline-flex;
            flex: 0 0 auto;
            font-size: 14px;
            font-weight: 650;
            gap: 7px;
            white-space: nowrap;
          }
          .battery-summary.warning {
            color: var(--accent);
          }
          .battery-summary svg {
            display: block;
            fill: none;
            height: 22px;
            stroke: currentColor;
            stroke-linecap: round;
            stroke-linejoin: round;
            stroke-width: 2;
            width: 22px;
          }
          .section-heading {
            display: flex;
            align-items: baseline;
            justify-content: space-between;
            gap: 16px;
            margin-bottom: 14px;
          }
          .gallery-heading-actions {
            align-items: center;
            display: flex;
            flex-wrap: wrap;
            gap: 10px;
          }
          .latest .section-heading {
            margin-bottom: 0;
          }
          .capture-browser {
            display: grid;
            gap: 14px;
            grid-template-columns: repeat(auto-fill, minmax(148px, 1fr));
          }
          .gallery-item {
            contain-intrinsic-size: auto 150px;
            content-visibility: auto;
            display: grid;
            gap: 7px;
            min-width: 0;
            overflow: hidden;
            position: relative;
          }
          .gallery-preview {
            appearance: none;
            background: transparent;
            border: 0;
            color: var(--fg);
            cursor: pointer;
            display: grid;
            font-family: inherit;
            gap: 7px;
            min-width: 0;
            padding: 0;
            text-align: left;
            width: 100%;
          }
          .gallery-thumb {
            aspect-ratio: 4 / 3;
            background: #e8e2d8;
            border: 2px solid transparent;
            border-radius: 14px;
            display: grid;
            overflow: hidden;
            place-items: center;
            position: relative;
            transition: border-color 140ms ease, transform 140ms ease;
          }
          .gallery-item:hover .gallery-thumb {
            transform: translateY(-2px);
          }
          .gallery-item.selected .gallery-thumb {
            border-color: var(--blue);
          }
          .gallery-thumb img {
            display: block;
            height: 100%;
            width: 100%;
            object-fit: cover;
          }
          .gallery-load {
            align-items: center;
            color: var(--muted);
            display: flex;
            flex-direction: column;
            font-size: 12px;
            gap: 7px;
          }
          .gallery-load svg {
            fill: none;
            height: 28px;
            stroke: currentColor;
            stroke-linecap: round;
            stroke-linejoin: round;
            stroke-width: 1.7;
            width: 28px;
          }
          .gallery-video {
            align-content: center;
            background: linear-gradient(145deg, #272b36, #46506c);
            color: #fff;
            display: grid;
            height: 100%;
            justify-items: center;
            width: 100%;
          }
          .gallery-video svg {
            fill: rgba(255, 255, 255, 0.22);
            height: 42px;
            stroke: #fff;
            stroke-linejoin: round;
            stroke-width: 1.5;
            width: 42px;
          }
          .media-badge {
            align-items: center;
            -webkit-backdrop-filter: blur(8px);
            backdrop-filter: blur(8px);
            background: rgba(20, 20, 20, 0.72);
            border-radius: 999px;
            bottom: 7px;
            color: #fff;
            display: inline-flex;
            font-size: 10px;
            gap: 4px;
            padding: 4px 7px;
            position: absolute;
            right: 7px;
          }
          .media-badge svg {
            fill: currentColor;
            height: 9px;
            stroke: none;
            width: 9px;
          }
          .gallery-caption {
            color: var(--muted);
            font-size: 11px;
            overflow: hidden;
            padding: 0 2px;
            text-overflow: ellipsis;
            white-space: nowrap;
          }
          .capture-info {
            display: grid;
            grid-template-columns: minmax(0, 1fr) auto;
            gap: 12px;
            align-items: center;
          }
          .capture-controls {
            display: flex;
            align-items: center;
            gap: 8px;
          }
          a.icon-button,
          button.icon-button {
            appearance: none;
            align-items: center;
            background: transparent;
            border: 1px solid var(--fg);
            border-radius: 50%;
            color: var(--fg);
            cursor: pointer;
            display: inline-flex;
            flex: 0 0 auto;
            height: 42px;
            justify-content: center;
            padding: 0;
            text-decoration: none;
            width: 42px;
          }
          button.icon-button {
            font-family: inherit;
          }
          .capture-stage .icon-button {
            background: rgba(247, 247, 244, 0.94);
            margin: 0 8px;
          }
          .icon-button svg {
            display: block;
            fill: none;
            height: 20px;
            stroke: currentColor;
            stroke-linecap: round;
            stroke-linejoin: round;
            stroke-width: 2;
            width: 20px;
          }
          button.icon-button:disabled {
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

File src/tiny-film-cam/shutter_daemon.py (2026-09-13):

from __future__ import annotations

import argparse
from dataclasses import dataclass
import logging
import os
import queue
import signal
import subprocess
import threading
import time
from pathlib import Path
from typing import Callable, Literal

from buzzer import (
    DEFAULT_PHOTO_SOUND,
    DEFAULT_PHOTO_VOLUME,
    DEFAULT_VOLUME,
    PHOTO_SOUNDS,
    ShutterBuzzer,
)
from camera import (
    AWB_MODES,
    CaptureSettings,
    VideoSettings,
    camera_is_available,
    capture_photos,
    capture_settings_from_env,
    record_video,
    resolve_project_path,
    video_settings_from_env,
)
from photo_filters import selected_photo_filter_from_cache


LOGGER = logging.getLogger("tiny_film.shutter")
DEFAULT_BUZZER_READY_DELAY_SECONDS = 5.0
DEFAULT_CAMERA_READY_POLL_SECONDS = 1.0
SYSTEMD_RUNTIME_PATH = Path("/run/systemd/system")


CaptureKind = Literal["photo", "video"]


@dataclass(frozen=True)
class CaptureRequest:
    request_id: int
    kind: CaptureKind
    requested_at: float


class CaptureRequestWorker:
    """Run every accepted button request in order on one camera worker."""

    _STOP = object()

    def __init__(
        self,
        *,
        take_photo: Callable[[], None],
        record_clip: Callable[[], None],
        clock: Callable[[], float] = time.monotonic,
    ) -> None:
        self._handlers = {"photo": take_photo, "video": record_clip}
        self._clock = clock
        self._queue: queue.Queue[CaptureRequest | object] = queue.Queue()
        self._state_lock = threading.Lock()
        self._next_request_id = 1
        self._accepting = True
        self._started = False
        self._thread = threading.Thread(
            target=self._run,
            name="tiny-film-capture-worker",
            daemon=True,
        )

    def start(self) -> None:
        with self._state_lock:
            if self._started:
                return
            self._started = True
            self._thread.start()

    def submit_photo(self) -> int | None:
        return self._submit("photo")

    def submit_video(self) -> int | None:
        return self._submit("video")

    def _submit(self, kind: CaptureKind) -> int | None:
        with self._state_lock:
            if not self._accepting:
                LOGGER.info("Ignored %s button press during shutdown", kind)
                return None
            request = CaptureRequest(
                request_id=self._next_request_id,
                kind=kind,
                requested_at=self._clock(),
            )
            self._next_request_id += 1
            self._queue.put(request)

        LOGGER.info(
            "%s request #%s queued (%s request(s) waiting)",
            kind.capitalize(),
            request.request_id,
            self._queue.qsize(),
        )
        return request.request_id

    def wait_until_idle(self) -> None:
        self._queue.join()

    def stop(self) -> None:
        with self._state_lock:
            if not self._accepting:
                return
            self._accepting = False
            self._queue.put(self._STOP)
            started = self._started

        if started:
            self._thread.join()

    def _run(self) -> None:
        while True:
            request = self._queue.get()
            try:
                if request is self._STOP:
                    return
                if not isinstance(request, CaptureRequest):
                    continue

                started_at = self._clock()
                LOGGER.info(
                    "%s request #%s started %.3fs after button press",
                    request.kind.capitalize(),
                    request.request_id,
                    max(0.0, started_at - request.requested_at),
                )
                try:
                    self._handlers[request.kind]()
                except Exception:
                    LOGGER.exception(
                        "Unhandled error in %s request #%s",
                        request.kind,
                        request.request_id,
                    )
                finally:
                    LOGGER.info(
                        "%s request #%s finished in %.3fs",
                        request.kind.capitalize(),
                        request.request_id,
                        max(0.0, self._clock() - started_at),
                    )
            finally:
                self._queue.task_done()


def env_bool(name: str, default: bool) -> bool:
    value = os.environ.get(name)
    if value is None:
        return default
    return value.strip().lower() not in {"0", "false", "no", "off"}


def env_int(name: str, default: int) -> int:
    value = os.environ.get(name)
    if value is None or value.strip() == "":
        return default
    return int(value)


def photo_button_pin_from_env() -> int:
    """Read the photo button pin, preserving the original env var as a fallback."""
    legacy_pin = env_int("TINY_FILM_BUTTON_PIN", 5)
    return env_int("TINY_FILM_PHOTO_BUTTON_PIN", legacy_pin)


def env_optional_int(name: str, default: int | None = None) -> int | None:
    """Read an optional int env var.

    Unset → ``default``. Explicit empty string → ``None`` (used to disable the
    buzzer while keeping the code default of GPIO 18 when the var is absent).
    """
    value = os.environ.get(name)
    if value is None:
        return default
    if value.strip() == "":
        return None
    return int(value)


def env_float(name: str, default: float) -> float:
    value = os.environ.get(name)
    if value is None or value.strip() == "":
        return default
    return float(value)


def parse_exposure_brackets(value: str) -> tuple[float, ...]:
    return tuple(float(part.strip()) for part in value.split(",") if part.strip())


def default_project_root() -> Path:
    return Path(__file__).resolve().parents[2]
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

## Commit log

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2026-06-11 Add Camera Module 3 capture CLI
    Adds a capture-only Picamera2 module and CLI for Raspberry Pi Camera Module 3 still photos, plus usage docs.
2026-06-11 Add UPS HAT to BOM
    Includes Uninterruptible Power Supply UPS HAT for Raspberry Pi Zero, ensuring stable 5V power output.
2026-06-14 Add mobile web capture
    Allow the phone web app to trigger a Tiny Film capture and share camera access safely with the physical shutter.
2026-06-14 Fix camera rotation handling
    [camera.py, capture.py, shutter_daemon.py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]
2026-06-14 Fix Pi camera color channels
    [camera.py, test_camera_rotation.py]
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2026-06-14 Replace capture list with carousel downloads
    Remove the bulk capture zip download and replace the captures section with a one-image carousel, arrow navigation, and a per-image download icon.
    [web.py]
2026-06-14 Update camera app header styling
    Rename and restyle the camera web app with a global monospace font, a compact battery summary in the header, and the Take Photo action in the Latest row.
2026-06-14 Tighten camera app section layout
    Hide the capture count line below Latest, reduce section heading size, move Battery above Device, and tighten Latest spacing.
    [web.py]
2026-06-14 Refine battery and device details
    Split battery metrics into two padded rows and trim Device details to App URL and Storage.
2026-06-14 Match detail font sizes
    Use shared label and value font sizes across battery metrics and detail rows.
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2026-07-04 Add Raspberry Pi Zero 2 camera case STL assets.
    Store the case base, top, and branded camera plate models for 3D printing the tiny-film hardware enclosure.
    [Raspberry_Pi_Zero_2_Case_MK3_Camera_camera-suv-text.stl, Raspberry_Pi_Zero_2_Case_MK3_Camera_top.stl, rpizerocase.stl]
2026-07-04 Add Printables source links for case STL assets.
    Document where the enclosure models came from alongside the files in assets/.
2026-07-07 Add C-shaped corner spacer bracket for Pi Zero camera mount
    3D-printable C-bracket (print 4x) to connect a Raspberry Pi Zero 2W
    to a camera mount with either 25mm or 20mm gap. 6.5x6.5mm pads,
    M2.5 screw holes, 2mm wall, filleted edges.
    [c_bracket_spacer.scad, c_bracket_spacer.stl, c_bracket_spacer_20mm.scad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]
2026-07-09 Add C-bracket spacer generation script and update SCAD file
    Introduced a new Python script to generate the 20mm C-bracket spacer STL with asymmetric hole sizes. Updated the SCAD file to define separate hole diameters for the bottom (2.1mm) and top (2.8mm) pads, ensuring accurate modeling for M2.5 screw clearance. A new STL file is now included in the assets.
    [c_bracket_spacer_20mm.scad, c_bracket_spacer_20mm_2.1_2.8.stl]
2026-07-11 Prepare the repo for public open source. (#16)
    Add an MIT license and Printables attribution, and scrub personal host details and stale tooling from the docs.
2026-07-11 Default capture rotation to 0.
    Matches the current camera mount orientation so photos are saved upright.
2026-07-11 Default capture rotation to 180.
    Matches the current camera mount so saved photos are upright.
2026-07-12 Refactor README to rename project and reorganize content
    Updated project title to "tiny-film-camera" and streamlined the README structure by moving the license information to a dedicated section. Enhanced the image alt text for clarity.
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2026-07-16 Add short video recording (#18)
    Add H.264/MP4 video capture alongside still photos across all capture
    paths, reusing the existing film-friendly image tuning.
    - camera.py: VideoSettings + record_video() using Picamera2
    create_video_configuration + H264Encoder + FfmpegOutput; video-only
    rotation (0/180) via libcamera Transform; video_settings_from_env
    - record.py: new CLI entry point (10s default)
    - web.py: POST /api/record endpoint, media-aware gallery, and Record 10s
    button with inline <video> playback for the latest and browsed clips
    - shutter_daemon.py: tap = photo, hold (1s) = record a clip
    - docs/README/setup: document ffmpeg dependency and new commands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
    [camera.py, record.py, shutter_daemon.py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]
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2026-07-19 Add Passive Buzzer Module to BOM documentation
2026-07-19 Add passive buzzer feedback for shutter captures (#19)
    Wire an optional PWM buzzer on GPIO 18 so the physical shutter can play
    five distinct cues (click, beep, chirp, alert, double), with a demo CLI
    for hardware bring-up.
    [buzzer.py, shutter_daemon.py, test_buzzer.py]
2026-07-19 Default shutter buzzer to GPIO 18 passive (#21)
    Enable feedback sound without requiring .env entries. Blank
    TINY_FILM_BUZZER_PIN or --no-buzzer still turns the buzzer off.
    [shutter_daemon.py]
2026-07-19 Fix buzzer test when gpiozero is installed (#22)
    Mock a missing gpiozero import so the degrade-gracefully case passes on
    the Pi instead of claiming a real pin and asserting the wrong state.
    [test_buzzer.py]
2026-07-19 Lower passive buzzer cue pitches slightly (#23)
    Shift the five shutter tones down within the module's 1.5–2.5 kHz range
    so feedback is a bit softer on the ear.
    [buzzer.py]
2026-07-19 Add mechanical shutter click-clack buzzer cue (#24)
    * Add mechanical shutter click-clack buzzer cue
    Approximate a camera shutter with a short high/low two-step pattern and
    play it when the physical button takes a photo.
    * Update buzzer docs heading for shutter cue
    ---------
    [buzzer.py, shutter_daemon.py, test_buzzer.py]
2026-07-19 Soften passive buzzer cues with low PWM volume (#25)
    Drive the passive module with a low duty cycle and shorter tones so shutter
    feedback stays quiet and pleasant by default, with TINY_FILM_BUZZER_VOLUME
    to tune it.
    [buzzer.py, shutter_daemon.py, test_buzzer.py]
2026-07-19 Control buzzer loudness with burst density (#26)
    Transistor-driven passive modules ignore PWM duty cycle, so volume now
    gates the carrier on/off. Lower TINY_FILM_BUZZER_VOLUME should finally
    sound quieter.
    [buzzer.py, shutter_daemon.py, test_buzzer.py]
2026-07-19 Tune buzzer cues for a calmer, softer feel (#27)
    Lower pitches toward 1.5 kHz, soften the shutter into a gentle descending
    settle, and drop the default burst volume so feedback stays quiet and calm.
    [buzzer.py, shutter_daemon.py, test_buzzer.py]
2026-07-19 Restore original buzzer cues with burst volume (#28)
    Bring back the first click/beep/chirp/alert/double tone set while keeping
    burst-density volume control so loudness stays adjustable.
    [buzzer.py, shutter_daemon.py, test_buzzer.py]
2026-07-19 Make buzzer cues audibly distinct (#30)
    [buzzer.py, test_buzzer.py]
2026-07-19 Set startup and photo buzzer cues (#31)
    [buzzer.py, shutter_daemon.py, test_buzzer.py]
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2026-07-19 Restore full buzzer volume default (#33)
    [buzzer.py, test_buzzer.py]
2026-07-20 Add pi-cam top cover STL file
    [pi-cam-top-cover-final.stl]
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2026-08-01 Use softer distinct volumes for ready and photo buzzer cues. (#36)
    Keep a gentle minimal ready tone and a quieter click at frame capture so shutter feedback stays light without waiting on JPEG save.
    [buzzer.py, shutter_daemon.py, test_buzzer.py]
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2026-08-02 Add detailed documentation for the SS23D32 three-position photo-filter switch plan
    This commit introduces a new markdown file outlining the goals, wiring, software design, delivery sequence, and acceptance checks for implementing a physical three-position selector for photo filters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
2026-08-04 Add new STL files for bottom cover, cam cover, and top cover
    This commit introduces three new binary STL files: bottom-cover-aug5-v2.stl, cam-cover-aug5.stl, and top-cover-aug5.stl, which are essential components for the project.
    [bottom-cover-aug5-v2.stl, cam-cover-aug5.stl, top-cover-aug5.stl]
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2026-08-07 Apply switch-selected photo filters (#38)
    * Add three-position filter switch input
    * Apply switch-selected photo filters
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2026-08-07 Update README and add new C-bracket spacer files
    - Updated README.md to reflect the new assembled camera image.
    - Modified assets/README.md for clarity on original project files and updated file names.
    - Added new C-bracket spacer files with different dimensions and generated corresponding STL files.
    - Introduced new Python scripts for generating C-bracket spacers.
    - Added a new image for how to fold the camera ribbon.
    [bottom-cover-aug5-v2.stl, c-bracket-20mm-gap-2.1mm-2.8mm-holes.scad, c-bracket-20mm-gap-2.1mm-2.8mm-holes.stl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]
2026-08-07 Add v1 assets section to README and include camera demo video
    - Updated README.md to include a new section for v1 assets.
    - Added descriptions for the bottom cover, camera cover, and top cover STL files.
    - Introduced a new camera demo video (cam-demo-1.mov) to showcase the project.
2026-08-07 Remove presets.py file containing image processing functions and presets for photo filters. This includes functions for vignette application, grain addition, and various image enhancements.
2026-08-07 Add v1 design image to README
    - Included a new image showcasing the v1 design of the tiny-film camera.
    - Updated README.md to reflect the addition of the v1 design section.
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2026-08-07 Document configuration and normalize assets (#40)
    [bottom-cover-aug5-v2.stl, bottom-cover-v1.stl, cam-cover-aug5.stl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]
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2026-08-08 Update wiring documentation to include passive buzzer setup
    - Modified `wiring.md` to add a section detailing the wiring for a passive buzzer, including pin connections.
    - Updated `README.md` to reflect the inclusion of the buzzer in the wiring guide link.
2026-08-08 Update video button GPIO pin in documentation and code
    - Changed the video button GPIO pin from 23 to 5 in `.env.example`, `setup.md`, `shutter-button.md`, `wiring.md`, and `buzzer.md`.
    - Updated the default value for the video pin in `shutter_daemon.py` and adjusted related tests in `test_shutter_daemon.py` to reflect this change.
    [shutter_daemon.py, test_shutter_daemon.py]
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2026-08-08 Enhance filter summary display in web page
    - Updated the filter summary text to include the switch position and fallback status in `web.py`.
    - Added a new test case in `test_photo_filters.py` to verify the correct display of filter and switch position on the web page.
    [test_photo_filters.py, web.py]
2026-08-08 Swap button pins and quiet capture buzzer (#44)
    [shutter_daemon.py, test_shutter_daemon.py]
2026-08-08 Replace wiring.jpeg with wiring.png for improved image quality in guides
2026-08-08 Remove filter-switch-plan.md as it is no longer needed; key information has been integrated into filter-switch.md for clarity and conciseness.
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2026-08-08 Update bottom and top cover STL files for improved design
    [bottom-cover-v1.stl, top-cover-v1.stl]
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2026-08-09 Update bottom cover STL file for version 1
    [bottom-cover-v1.stl]
2026-08-10 Delay startup buzzer until system settles (#51)
    [buzzer.py, shutter_daemon.py, test_shutter_daemon.py]
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2026-08-16 Fix formatting in camera description for clarity
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2026-08-22 Fix README CAD preview and wiring image (#64)
    * docs: fix CAD preview and wiring image
    * docs: move design sections below overview
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2026-09-04 Replace cool filter with cinematic grade (#78)
    [photo_filters.py, test_photo_filters.py]
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
